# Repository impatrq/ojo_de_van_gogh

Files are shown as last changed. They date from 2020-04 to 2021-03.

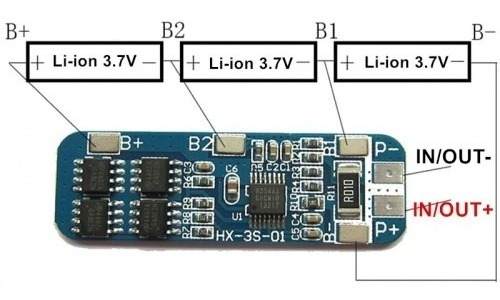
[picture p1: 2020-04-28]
modulo_de_carga/Diagrama_de_conexion/Cargador_de_pilas/Como-conectar-pilas.jpg

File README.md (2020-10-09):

# Ojo de van gogh

Este proyecto esta hecho con el fin de crear un **sistema de ayuda a la gente con discapacidad visual** para, a través de inteligencia artificial, **reconocer objectos que no pueden ver**. 

Se compone de un sistema electrónico que va colocado en el antebrazo y lleva una camera que se coloca en la mano. Cuando el ciego, por ejemplo, parpadea dos veces el sensor cerebral entiende su intencionalidad de querer sacar una foto y se lo comunica a la raspberry, esta actua sacando una foto y la procesa con **google vision API** para luego dar una respuesta del texto que se lee en la foto, el objeto que aparece o los colores predominantes

## Requisitos

Para ejecutar este proyecto se debe contar con estos requisitos:

- Hardware: elementos electronicos fisicos para crear el sistema.
  - Mindwave
  - Arduino Nano
  - Raspberry Pi Zero
  - Pi camera
  - Cargador portatil pequeño (ver PCB)
  - Dos buzzers
- Software: lenguajes requeridos para poder llevar a cabo esta idea
  - Python 3.7
  - Arduino IDE

## Instalación

#### Raspberry:

Para ejecutar la instalación debemos pararnos en la carpeta raiz del proyecto y ejecutar

```shell
pip install -r requirements.txt
```

Luego de ejecutar esto contamos con las dependencias para que la raspberry trabaje de manera correcta. 

#### Arduino:

Para ejecutar la instalacion procedemos a conectar el arduino a nuestro computador y seleccionamos el puerto correspondiente y enviamos el archivo "mindwave.ino" que se encuentra en la siguiente ruta *ojo_de_van_gogh\placa_electronica\arduino_code*

## Autores de este repositorio 

- **CARRO, Nahuel Agustín** - *PCB, Arduino y Raspberry* - [NahuelCarro](https://github.com/NahuelCarro)
- **PIERRI, Matias Gabriel** - *PCB, Arduino, Raspberry y Case3D* - [matias1379](https://github.com/matias1379)
- **VILARDO, Theo** - *Raspberry* - [TheoVilardo](https://github.com/theovilardo)
- **FONTE, Gonzalo Juan** - *Case3D* - [gonzafonte](https://github.com/gonzafonte)

## Colaboradores

- **MEDINA, Sergio** - *Supervisor desarrollo proyecto* - [sergiomedinaio](https://github.com/sergiomedinaio)

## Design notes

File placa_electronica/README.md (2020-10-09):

# Placa electrónica

Esta carpeta contiene los códigos de programación necesarios para crear el sistema, además de las conexiones para fabricar el circuito electrónico.

Vamos a encontrar las siguientes carpetas:

- **Arduino code**: Esta carpeta contiene los códigos de programación que se deben colocar en Arduino NANO usando el Arduino IDE. El código se hace utilizando la metodología de creaciones de clases de C++
  - Mindwave.ino: Este programa se va a encargar de procesar la informacion del sensor cerebral y comunicarle a la raspberry en que momento se detecto un doble pestañeo intencional del usuario
  - códigos_auxiliares_ejemplo: Aquí se encuentran códigos de programación que nos ayudaron a desarrollar el código *mindwave.ino*
- **PCB Ojo de Van Gogh**: Esta carpeta contiene los archivos de KiCAD del PCB junto a su esquemático, además cuentan con una carpeta de *huellas* con las dependencias que necesita
- **Raspberry code**: Esta carpeta contiene los códigos de programación que deben ser cargar en la Raspberry Pi Zero:
  - main.py: es el código que debe ser cargado y ejecutado en la raspberry. Se encarga de recibir la orden del Arduino NANO y generar la acción que el usuario elije previamente
  - clases: Aquí se encuentran las clases que se llaman en el main.py ya que usamos OOP
  - códigos_auxiliares_ejemplo: Aquí se encuentran códigos de programación que nos ayudaron a desarrollar el código *main.py y sus clases*

**WARNING**: Hay un .gitignore que tiene seteado que no debe subir al repositorio las **credenciales de Google Vision API** ya que es información sensible y cada uno debe colocar la credencial correspondiente al clonar el repositorio. **Si no se agrega esta credencial el main.py fallará**

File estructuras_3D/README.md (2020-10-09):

# Estructuras 3D

Esta carpeta es un apartado a las estructuras 3D que hicimos en AutoCAD 2007. Dentro de esta carpeta van a encontrar:

- **Logotipo 3D**: Aqui esta el logo en 3D para colocarlo en nuestro producto para hacer un establecimiento de la marca
- **PCB case**: Aqui estan los archivos CAD correspondientes para la estructura que va a encapsular el PCB. Notese que al abrir esta carpeta hay un CAD con la estructura completa y otros CAD que son esta misma estructura cortada al medio a fin de poder imprimir medio *case*, insertar el pcb y luego pegar la otra mitad del *case* arriba

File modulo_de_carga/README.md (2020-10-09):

# Modulo de carga

Esta es una idea en **etapa experimental** de, ademas del sistema de reconocimiento visual del ojo de van gogh, crear un cargador de baterias que indique con un sonido cuando estas se cargaron al maximo ya que el usuario con discapacidad visual no cuenta con los medios para recibir ese *feedback* de que se cargo su bateria

Dentro de esta carpeta se encuentran:

- **Diagrama de conexion**: Aqui se van a encontrar los esquematicos y pcb de este modulo de carga. Notese que hay una carpeta que contiene los simbolos y huellas que requieren estos archivos de KiCAD

- **Diseño de estructura**: Aqui se van a encontrar lo archivos CAD correspondientes al diseño de la estructura de este modulo de carga. Notese que se encuentran en dos formatos:

  - CAD(autoCAD 2007)
  - PDF

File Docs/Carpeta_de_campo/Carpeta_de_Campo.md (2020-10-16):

# Carpeta de Campo 

## Semana 15/03 - 22/03

Escribimos una declaración jurada sobre la compra del NeuroSky Mindwave debido a que Matías Pierri tuvo la oportunidad de que un conocido se lo compre en USA Y abaratar costos

> Clic [aqui](https://github.com/impatrq/ojo_de_van_gogh/blob/develop/Docs/Carpeta_Tecnica/DeclaracionSensor.pdf) para ver la Declaración Jurada

### NeuroSky Mindwave

Es una diadema con biosensores de electroencefalografía que permite hacer la medición de las ondas eléctricas del cerebro y vincularse a diferentes aplicaciones para investigación, entrenamiento cognitivo y bienestar.

El NeuroSky MindWave Mobile 2 mide y emite de forma segura los espectros de potencia EEG (ondas alfa, ondas beta, etc.), los medidores NeuroSky eSense (atención y meditación) y los sensores para el parpadeo de los ojos. El dispositivo consta de un auricular, una orejera y un brazo sensor, los electrodos de referencia y de tierra del auricular están en la pinza para la oreja y el electrodo EEG está en el brazo del sensor, apoyado en la frente sobre el ojo. 

En nuestro caso, lo vamos a usar para que cuando la persona parpadee se active el sistema.

mindwave

### Motor vibrador

Investigamos sobre vibradores y llegamos a la conclusión de que lo mas viable es reciclar vibradores de teléfonos viejos como los Nokia. Un motor vibrador es un motor común en el cual se le pone un peso en la punta del émbolo lo que lo hace vibrar, además se coloca dentro de un contenedor que aumenta la vibración.

vibrador

### Conexión entre BT y Arduino

Establecimos el entorno de trabajo BT con Arduino usando los HC-05. En base a las conclusiones confeccionamos una guía de como usar dicho entorno 

arduino_bt

> [Guía de como Establecer conexion entre BT](https://github.com/impatrq/ojo_de_van_gogh/blob/develop/Docs/Carpeta_de_campo/Guias_md/Entorno%20de%20trabajo%20de%20Arduino%20con%20Bluetooth.md)

Usando Arduino logramos hacer que funcionen los vibradores extraídos del Nokia usando la función Tone() and noTone() que te permite poner la frecuencia de vibración la cual va a variar según lo que se necesite

> [Guía de Sistema de vibracion](https://github.com/impatrq/ojo_de_van_gogh/blob/develop/Docs/Carpeta_de_campo/Guias_md/Sistema%20de%20Vibraci%C3%B3n.md)

Como la Raspberry se maneja con JSON estuvimos aprendiendo a como procesar un string JSON en Arduino y poder hacer el intercambio de datos entre Raspberry y Arduino por BT. Nos dimos cuenta que para que se lean bien los datos hay que usar Serial.readString() ya que Serial.read() solo detecta que entra un char 

> **JSON** (acrónimo de  JavaScript Object Notation, «notación de objeto de JavaScript») es un  formato de texto sencillo para el intercambio de datos.

Empezamos a trabajar con el sensor cerebral conectado a un teléfono y logramos que cuando parpadee el usuario, el teléfono lo detecte pero esto es una app y no nos permite tocarla mucho para usarla en nuestro Arduino pero era a modo de primeros pasos. Usando un modulo bluetooth y comandándolo por AT tratamos de configurarlo insertando los siguientes datos

> Baudrate = "576000"
>
> BIND ADDR= "0081,f9,29eb31"
>
> PSSW = "1234"

Con esta configuración no funciono ya que la password estaba mal puesta. Viendo la documentación nos dimos cuenta que la pass es 0000

> PSSW CORRECTA ="0000"

Ya de esta forma pudimos conectar el Arduino con el HC-05 pero con el example que nos da el fabricante solo podemos medir nivel de atención y relajación. Tenemos que investigar como medir nivel de pestañeo. Sin embargo hicimos una prueba donde se prenden leds de acuerdo a que tan concentrado esta el usuario

Establecimos el entorno de trabajo en Google Visión IA que es usar la Nube de Google para, a través de un sistema de redes neuronales, obtener un análisis de lo que se ve en una foto. Para esto tuvimos que crear un proyecto en Google Cloud Services y habilitar la api de Google Visión AI. Una vez habilitado esto nos dan un archivo JSON que tiene nuestra API Key y la insertamos en la Raspberry usando 

```Raspbian Terminal
export GOOGLE_APPLICATION_CREDENTIALS=/home/pi/filename.json
```

Una vez seteada la Raspberry se usan los siguientes comandos para instalar las dependencias necesarias

```Linux Terminal
   python3 -m pip install --user pip
   python3 -m pip install --user google-cloud-vision
   python3 -m pip install --user Pillow
   python3 -m pip install --user picamera
```

Usamos este comando para sacar una foto 

```RAspbian
   raspistill -o cam.jpg
```

Y este ejemplo para poder probar el análisis de la foto 

```Raspbian terminal
python3 camera_vision_face.py
```

Nos devuelve este análisis donde la Raspberry se encargo de detectar las personas que aparecen en la foto en este caso Theo. Lo borroso de la foto se debe a que Theo tiene el celu que no enfoca, la definición en si de la Pi Camera es bastante buena

theo

Ahora tenemos que ver como usar la Raspberry para conectarla al BT y además que todos estos programas que describimos antes estén funcionando en Loop y de forma automática cuando se prende la Raspberry.

## Semana 22/03 - 29/03

Estuvimos viendo documentaciones y aparentemente para poder leer el valor de Blink Strength tenemos que escribir en el registro **0x16** 

registros_mindwave

Se hicieron ejemplos con Arduino para empezar a leer los datos Json que se recibirán de la Raspberry. Se han hecho pruebas de como formar un Json y como obtener el valor de Json.
Luego se probo mandar archivos String por BT, pero nos dimos cuenta que la función no permite mandar Strings por BT:

```
BTMaster.write()
```
Se ha visto varios videos o formas de intentar mandar el String por BT de otra forma, pero no se ha conseguido, entonces se empezó a investigar para pasar un String a un char Array. Se ha encontrado un ejemplo en el que muestra que la función: 
```
str.toCharArray(charArray,buf)
```
Siendo str el String ingresado, charArray, la variable donde se guarda el charArray y buf la cantidad máxima a convertir de String en char Array.

Se ha tenido problemas con esta función ya que dependiendo del orden en el que se declaraba el String, funcionaba o no. Pero se ha logrado descubrir el error, creando 2 programas: 
-	Uno que simula el parpadeo, sacar foto y mandar el String Json por BT a través de un charArray
-	El otro que recibe el char Array y lo convierte en un String, y obtiene el valor del Json de color y de acuerdo al color realiza una vibración

> [Sistema de vibraciones con Json y BT](https://github.com/impatrq/ojo_de_van_gogh/blob/develop/Docs/Carpeta_de_campo/Guias_md/Sistema%20de%20vibraciones%20de%20acuerdo%20al%20color.md)

Hemos realizado el logo para el proyecto:



## Semana 29/03 al 05/04
Se crearon las piezas en 3D del cargador de pilas. Las piezas están diseñadas teniendo en cuenta las plaquetas que van a ir colocadas y están los agujeros para los respectivos cables.

**Cargador parte 1**

cargador_1

**Cargador parte 2**

cargador_2

**Cargador parte 3**

cargador_3

Analizamos el problema que creamos en el repositorio de Ojo de Van Gogh ya que nos mezclamos con el manejo de branches y mil problemas entonces decidimos crear repositorios por cada área de trabajo del proyecto y los archivos de documentación y publicidad manejarnos por drive. 
Los repos quedan de la siguiente manera:

- Mindwave
- ArduinoVibrador
- Raspberry
- Cargador de pilas

Ahora nos manejamos con ramas donde la versión final y estable del repo va a Máster y luego cada feature se desarrolla en una rama paralela. Luego de hacerle el testing a la misma y ver que no hayan conflicto se hace un merge (se fusiona la rama con el máster y se cierra la rama)

Con respecto al mindwave decidimos poner en pausa el código del micro porque nos estábamos perdiendo con el tema del payload. Encontramos varios repos en github con los códigos en Python donde al ejecutarlos te otorgan los datos. El plan es conectar por BT el mindwave a la computadora y correr el script. Una vez que el mismo este listo 

Nos estamos contactando con varias empresas preguntando sobre plaquetas flexibles para el sistema de vibración aunque también se esta evaluando la opción de utilizar los brazaletes porta celulares para correr. Se ha realizado el PCB del sistema ya que una empresa nos contacto y nos lo pidió para saber el tamaño y complejidad.

## Semana 05/04 al 12/04

Hemos recibido las respuestas de las empresas por plaquetas flexibles y nos ha parecido muy elevados los costos por lo cual optamos por usar un brazalete para celulares de un tamaño de 18cm x 10 cm y se ha realizado el esquemático del circuito donde estará la Raspberry con la cámara, el Arduino Nano, el Bluetooth, dos pilas, un regulador y los vibradores.

Hemos calculado el consumo total del circuito para saber que tenemos que usar dos pilas de 3.7V ya que con una nos duraría poco tiempo, y por esto se ha investigado sobre Step down, ya que tiene mejor rendimiento que un regulador, ya que se necesitan 5V de entrada en vez de los 7.4V que nos dan las dos pilas en serie.

También se ha realizado una librería para los colores en Arduino, y hemos encontrado el problema que si haces un archivo con la extensión:  ".c " salta un error y se soluciono esto cambiando la extensión del archivo a ".cpp"

Se ha investigado sobre el mindwave y el funcionamiento de un programa y se ha conseguido que se detecte el parpadeo pero también se detecta el parpadeo no forzado y para eso estamos viendo como solucionarlo.

Se ha conseguido que la Raspberry nos entregue el color en RGB con Json

Se ha comprado un dominio y estamos haciendo la pagina web a través de un localHost (Xampp) y usando WordPress. Se ha elegido el tema de la pagina que es BlackootLite.
## Semana  12/04 al 19/04

Se ha terminado el PCB de la placa

Montamos el host en 000webhost que nos ofrece 300 Mb de espacio y le instalamos wordpress. Tuvimos problemas con el dominio así que contactamos a soporte técnico de hostinger y nos solucionaron el problema.

> Clic  [aqui](https://ojodevangogh.tech) para entrar a nuestra pagina

Encontramos un modulo de Python que pasa de RGB a nombre de color y funciona pero tienen sus limitaciones. El tema es que no da resultado a todos los RGB sino a los que son fáciles tales como  0,0,0 que da black pero si le metemos algo como 65,23,19 ya se pierde.

Encontramos una alternativa basándonos en la página de un sensor de color que nos otorga Luis llamas 

> [Sensor para Detectar colores](https://www.luisllamas.es/arduino-sensor-color-rgb-tcs34725/)

Acá muestra un sensor para detectar colores y en esta usan una librería que pasa los valores RGB a HSV que nos permite saber las distintas tonalidades de un color ya que distingue de rojo oscuro y rojo claro y nos permite tomas los dos como rojo. Esta librería la pasamos a Python y gracias a esto ya poseemos 12 colores identificables

Hemos realizado la librería para la vibración de los colores y para esto hemos creado una tabla para determinar la vibración de cada color:

**Lista de colores para vibración**

- El número 0 representa 0.25 segundos de duración de vibración
- El número 1 representa 1 segundo de duración de vibración 
- Entre cada numero hay 0.25 segundos de pausa
| Código | Colores  |
| :----: | :---: |
|  0000  |  Blanco  |
|  0001  | Rojo |
|  0010  |  Marrón  |
|  0011  | Naranja  |
|  0100  | Amarillo |
|  0101  |  Verde |
|  0110  | Cian |
|  0111  | Azul |
|  1000  | Violeta  |
|  1001  | Rosa |
|  1010  | Gris |
|  1011  | - |
|  1100  | - |
|  1101  | - |
|  1110  | - |
|  1111  |  Negro |

La pagina web se nos cayó. Nos suspendieron la pagina porque aparentemente superamos el limite de visitas al entrar a verla y nos dicen que si no pagamos en 7 días nos la borran.

Nos comunicamos con webhost a ver si hay alguna alternativa pero no nos contestan así que no nos queda otra que pagar y mudarnos a hostinger

**Logo 3D**

Se ha hecho el logo en formato 3D para después agregarlo como marca en la caja que tengamos.

logo_3D

## Semana 19/04 al 25/04

Pagamos la migración de nuestro página a hostinger que nos salió 10 dólares. Tenemos que esperar 48 hs a que nos digan si salió todo bien y no perdimos la pagina.

Recuperamos la pagina y esta todo en orden aunque se nos desconfiguró el dominio y tenemos que cambiarlo así responde a ojodevangogh.tech . Eso si, no podemos entrar al panel de wordpress por alguna razón.

Nos comunicamos con hostinger y después de unos largos idas y vueltas de email mudamos completamente la pagina ya no tenemos nada en webhost esta todo en hostinger y funciona todo. Habilitamos la certificación ssl así que nuestro pagina es segura y ya tenemos acceso al panel de wordpress. 

Tenemos un problema en el responsive desing que hace que desaparezcan los botones de la página cuando usamos una versión mobile y no sabemos que hacer

## Semana 25/04 al 3/5

Vimos que no había manera de solucionar el responsive design mas que pagar el upgrade del theme de wordpress a premium que son 40 dólares así que decidimos cambiar de tema de Wordpress. 

Empezamos la búsqueda y encontramos uno llamado astrid que esta muy bueno visualmente y tiene mucha opción de personalización. Lastimosamente no podíamos cambiarle el fondo blanco así que para que no queme tanto le colocamos letra Arial que es mas gruesa y llama la atención.

Le instalamos un plugin a la pagina para que aparezcan botones que vinculen la página con Instagram, LinkedIn llamado UltimateShare.

Creamos una pagina de Instagram para empezar a subir cosas y ya grabamos unos videos de como la Raspberry reconoce colores y como a través de un color seleccionado funcionan los vibradores

Para un mejor orden creamos un repositorio nuevo donde metimos todas las cosas de los pequeños repos a través de git flow que permite ordenar todo en feature.

Para armar cosas lindas para redes sociales hicimos que la plaqueta tenga todos los micros y cosas con modelos 3D así verlos con el visor 3D de KiCAD

## Semana 03/05 al 11/05

Se hizo una introducción para el video en After Fx, se le puso música de fondo y se subió a Instagram y a la pagina web el primer video mostrando como se reconoce el color con la cámara de la Raspberry

También se definió el modelo para hacer la tapa del cargador de pila y se empezó a hacerla. 

Se agregó un plugin para que la pagina cargue mas rápido y se corrigió el logo para que no sea de fondo blanco y pueda verse. 

## Semana 11/05 al 18/05

Se empezó a intentar conectar la Raspberry con el sensor cerebral y se configuro esta para que trabaje por Remote

Agregamos con gtts para que se pueda escuchar el color y lo probamos con un parlante y anduvo. Para traducir el texto color a voz se creo una nueva función que envía archivo txt que los recibe el gtts y los reproduce en un parlante

Para la PRIMER ENTREVISTA DE RADIO, se realizo una tarjeta publicitaria que se subió a Instagram y como se escucho bajo, se edito el  audio grabado y se preparó para subirlo a IGTV y quedamos en que cuando la situación del país lo permita, nos volveremos a juntar para contar los nuevos avances.

Se daño el disco de la computadora y perdimos lo que teníamos hecho de la tapa y no se había subido a git.

## Semana 18/05 al 25/05

Se pudo conectar el sensor cerebral con la Raspberry pero no lee el payload del Mindwave y estamos con ese problema que no sabemos como resolverlo

Se hizo un Backup de la pagina web porque se nos vencía el mes de Hostinger pero debido a un error que tuvieron nos regalaron un mes y ya elegimos que para el mes próximo vamos a cambiar al host de Sitio Hispano que nos saldría $860 el año ya que no se puede pagar por mes

Estuvimos pensando y se nos ocurrió que nuestra pagina tiene que tener para que los ciegos la puedan leer, entonces agregamos el Plugin Responsive Voice que permite a través de un botón reproducir el contenido de cada pagina.

Se edito y subió el IGTV de la nota de radio y también subimos el link de la pagina que hizo la radio FM106.5 sobre esta nota. 

Se terminó la tapa y se empezó a realizar el encastre en la caja.

Se crearon archivos txt para el gtts para optimizar los tiempos de respuesta cuando se reproducen los colores, ya que lee los archivos creados en vez de crearlos y después leerlo.

## Semana 25/05 al 1/06

Se logró la comunicación entre el Arduino y la Raspberry y creamos 2 librerías una para detectar colores y otra para crear un JSON. Esto se hizo para ordenar el código. A la librería de detectar_colores también se le incorporó los audios para reproducir el color. 

Se investigó como hacer que cada vez que la Raspberry se enciende empiece a correr el script automáticamente sin ponerle el comando utilizando Crontab.

> [Script para automatizar inicio](https://github.com/impatrq/ojo_de_van_gogh/blob/develop/Docs/Carpeta_de_campo/Guias_md/Correr%20script%20cada%20vez%20que%20se%20prenda%20la%20Raspberry.md)

Se ha logrado pasar las fotos a formato base64 para reducir tiempos de espera y se logro una optimización. Antes tardaba 24 segs y ahora tarda entre 16 y 20 segs, siendo un factor clave la luz ambiente, ya que si hay poca luz tarda mas. 

Se ha investigado e implementado en la página web sobre plugins de accesibilidad, se han probado varios pero el que mas herramientas nos proporciona es UserWay, Este plugin tiene varias herramientas
- Permite 3 niveles de lector de pantalla(medio, rápido y despacio).
- Navegar por teclado (accesibilidad para ciego y poca motriz)
- Cambiar los contrastes de fondo (gris, invertido, oscuro y claro)
- Permite resaltar enlaces
- Aumentar el tamaño y el espaciado del texto y también del cursor
- Detener animaciones
- Cambiar la letra para la gente que padece dislexia
- Aumentar el cursor y tener una guía de lectura
- Y por ultimo ofrece resetear todas las opciones

accesibilidad

Se ha avanzado con el modelado 3D de la caja que contiene el proyecto, modificando los espacios para las pilas ya que no iban a entrar con el que tenía y se avanzó con el encastre de la tapa con la caja agregando los agujeros en la misma. 

## Semana del 1/06 al 8/06

Se editó y musicalizó un segundo video para subir a las redes , el cual mostrara como al reconocer un color empezaría a reproducirse un sonido/vibración.

Se subió a ig historias de quienes somos y una breve descripción del proyecto, dejando estas mismas como destacadas y se aumento 16 seguidores .

Se hicieron varias pruebas para empezar a reconocer texto y con el código que ofrece la api no lográbamos poder reproducir el texto, entonces hemos buscado otro código el cual nos permitió reproducir el texto que reconoció de la imagen que le cargamos a la Raspberry

Se han buscado diferentes librerías para hacer una lectura de OCR mas rápida pero no se encontró, y viendo videos y características, hemos decidido pasar de la Raspberry Pi Zero w a la Raspberry Pi 3 y hemos tenido las siguientes mejoras:
- Reconocimiento de colores en  5 segs
- Reconocimiento de texto entre 7 y 11 segs
- Reconocimiento de objetos en 10 segs

Se hizo un código para reconocer objetos obteniendo el objeto con mayor seguridad. Se ha agregado para que el objeto sea traducido ya que la librería da el resultado en ingles. Hemos aprovechado esto para darle una herramienta mas al proyecto y permitir que cuando una persona quiera leer texto que no sea español, sea traducido y sea reproducido por el auricular. 

Se ha instalado el plugin Yoast que sirve para saber que características faltan para mejorar el SEO de la pagina (optimización de los buscadores). Luego se ha procedido a cambiar la página de inicio agregando información y cambiando títulos de acuerdo a la palabra clave ingresada "ciego ven colores". 

Debido a que la actividad cerebral de cada persona es distinta y no se puede tomar una medida precisa para usar cuando se parpadea, hemos empezado a investigar sobre desviación estándar.
Para ver el grafico de la desviación estándar se investigo sobre la librería pandas pero después vimos que no era necesario y teníamos problemas con el ajuste de escala. 
Se hizo un graficador de las ondas cerebrales a través de Arduino usando Matplotlib y hemos visto que la desviación estándar con 2 parpadeos no es tan estable ya que varia entre 50 y 60 pero cuando la persona parpadea 3 veces es mucho mas estable dando unos valores de 80. 

Se termino con el diseño 3D de la caja y tapa agregando un encastre para que entre a presión, quedando lista para su impresión. 

### Tapa de la caja

tapa_caja

### Caja por dentro

caja

## Semana del 8/06 al 15/06

Se crearon librerías para tener el código mas prolijo.
- Librería de reconocimiento de texto tanto en español como en otro idioma, ya que tiene la opción de que cuando se reconozca que es otro idioma sea traducido 
- Librería de reconocimiento de objetos, dando el contenido en español. 

Se agrego para que se pueda reconocer la ubicación de dichos objetos detectados y limitando a que te diga solo los que la api detecta con una buena precisión (score). 

Se ha mejorado la pagina "El proyecto", basándonos en las características de mejorar la legibilidad y algunas cuestiones de SEO. 

## Semana del 15/06 al 22/06

Se grabo un video mostrando el reconocimiento de colores, objetos y leyendo un texto. Luego se agregaron efectos especiales

Se hizo una publicación para IG por la entrevista que tuvimos el viernes, y se edito el video , musicalizo y se subió a IGTV . Nos hemos contactado con ASAC y estamos esperando la respuesta. 

Mudamos la pagina a un nuevo host (SitioHispano) que nos salió 860 $ el año

Se ha detectado cuando entra información del Mindwave para tomar el valor promedio de la persona en los primeros segundos.

Se adapto para que se reconozcan los 2 colores que mas ocupan en la foto y luego ordenarlo para que primero este el que mejor se reconoció (score mas alto). 

Se actualizo la librería de objetos, agregándole la ubicación del mismo

## Semana del 22/06 al 29/06

Se hizo una librería para el código de Mindwave para que quede mas ordenado.

Se incluyo en la librería de RGB para que se pueda reconocer 2 colores si la diferencia de score es menor a 0.10 

En la pagina web, agregamos los slider en la paginas de noticias para que sea mas cómodo y lindo.

Se hizo el anuncio para la radio 99.3 FM que sale el viernes y se ha publicado con la edición de musicalización el tercer video mostrando el reconocimiento de colores, texto y objetos

Se nos ocurrió para mejorar la calidad del reconocimiento de colores, crear una tabla de Excel y copiar los 140 colores que nos da la pagina de Wikipedia con sus RGB y sus nombres. Luego exportamos esa tabla a pandas y hemos agregado 2 condiciones para los colores negro y blanco.

## Semana del 29/06 al 06/07

Se subió el IGTV de la entrevista de la radio y también se ha subido a YouTube y a la pagina web.

Se agrego dos condiciones de blanco y negro para descartar mas rápido y si no se cumplen que recorran el código a través de búsqueda binaria en Rojo, haciendo que el código sea mas rápido.

Hemos puesto que si no se encuentra algún color en la tabla, se agregue ese valor a la misma .Luego será revisado por alguno de los integrantes, clasificándolo y quedando la tabla ya actualizada.

También hemos probado algunas fotos y clasificando los colores que no se han reconocido.

## Semana del 06/07 al 14/07

Se incluyo en la pagina web un mensaje de bienvenida y también un nuevo símbolo cuando las paginas están cargándose.

Se ha contactado nuevamente con ASAC y MasScience y nos prometieron publicar pronto un articulo nuestro en su pagina. Se ha mandado mails tanto a medios nacionales como radios.

Se normalizaron todos los códigos haciendo que todos queden con la misma estructura de pedir el dato a obtener: color, texto u objeto.

Se ha creado una clase de búsqueda binaria y ordenado el main. Se creo una nueva clase llamada Google Vision Engine .
En esta clase se han creados los métodos de 

- Pedir color
- Elegir ese color(query)
- Leer texto y reproducirlo
- Reconocer objetos y su ubicación

Nos hemos dado cuenta de que muchas variables y partes de código que no se usaban y las hemos borrado.

Hemos agregado para que cada valor nuevo en la tabla, se reorganice de menor a mayor y se actualicen los id 

Se preparo la encuesta en Google forms  para saber que piensan las personas sobre el proyecto.

## Semana del 14/07 al 21/07

Se ha realizado nuevamente el PCB, ya que hemos agregado el switch de 4 posiciones para que la persona elija una función del proyecto. También se ha reemplazado las pilas de litio y regulador de tensión y pusimos una entrada para un cargador portátil común.

**PCB Terminado**

placa

pcb

esquematico

Se ha investigado para agregar que se corrijan las palabras cuando se las reconoce mal pero con la librería Textblob era muy irregular y decidimos no usarlo.

Se paso el código de vibración, realizado en Arduino a Python para controlar el buzzer con la Raspberry. Esto se realizo ya que si quisiéramos que el Arduino realice las vibraciones, se pierde tiempo para captar la señal que proviene del Mindwave. También se creó una función para que se pase de texto a audio

Se realizo la encuesta y hemos sacado buenas conclusiones sobre los datos obtenidos a través de las respuestas.

## Semana del 21/07 al 28/07

Semana de descanso por receso escolar de invierno.

## Semana del 28/07 al 04/08

Hemos investigado sobre lo que seria nuestro cliente ideal y tareas que quiera realizar, observando los beneficios y miedos o frustraciones de realizar dicha tarea. Una vez realizado esto, hemos planteado sobre las situaciones que le dan alegría y tristeza al cliente y que ofrecemos nosotros como producto y servicio.

Vamos a empezar a realizar entrevistas a personas con ceguera y hemos planteado como tienen que realizarse, lo que no hay que hacer y recomendaciones.

Hemos encontrado una tabla con 865 colores con sus nombres, valores hexadecimales y valores R,G,B y hicimos un código con dicha tabla buscando el color en la tabla que tenga menos diferencia con el color buscado.

Nos ha contactado la página de MasScience para decirnos que publicaron en su página un artículo sobre nuestro proyecto. 

> Clic  [aqui](https://www.masscience.com/2020/07/21/proyecto-ojo-de-van-gogh/) para ver el artículo del proyecto

## Semana del 04/08 al 11/08

Se ha creado el método de audio y se agrego a la clase principal llamada Google Vision Engine, que es la clase que contiene todos los métodos. Una vez agregado la clase de audio se ha usado en los métodos de texto, objetos y color, para que se reproduzca por un parlante, el parámetro que se pida .

También nos hemos contactado con algunas personas que padecen ceguera para poder hacerles una entrevista y verificar cuales son los problemas principales de estas personas en el día a día, y con esto nos han confirmado lo siguiente:
- Ellos se frustran no tener un sentido asociado al color y se preguntan que es, y al vivir en un mundo que se ve tienen que saber como vestirse pero para ellos es lo mismo la combinación de colores. También buscan relacionar los colores con objetos, por ejemplo que el rojo es del fuego
- Les molesta cuando las situaciones no tienen audios descriptivos. Y para cuando tienen que ir a comprar necesitan alguien que les diga cuanto sale y cuando es la fecha de vencimiento
- El reconocimiento de objetos para ellos es muy importante, ya que no pueden saber que hay cuando les mandan una foto, y si quieren ir a comprar necesitan de alguna persona para saber donde esta lo que ellos buscan.

## Semana del 11/08 al 01/09

Semanas para rendir exámenes y entrega de trabajos prácticos.
Hemos hablado de los pasos a seguir del proyecto:

- Armar guion y video para presentar el proyecto
- Hacer un diagrama de arquitecturas para organizar el código.

## Semana del 1/09 al 8/09

Luego de haber hablado con el profesor durante varias semanas de como seguir y que mejoras tendríamos que hacer, hemos empezado por reorganizar el código. Para eso hemos armado un diagrama de arquitecturas definiendo todas las clases padres e hijas

diagrama_arquitecturas

Hemos traducido el dataset de 860 colores para evitar traducirlo y hacer que el código sea mas rápido 

## Semana del 8/09 al 15/09

Hemos realizado el refactoring de la clase de colores y un conteiner de Docker para poder hacer un despliegue a producción

Hemos empezado a investigar sobre como se arma un video para poder presentar nuestro proyecto y hemos planteado los puntos principales que tiene que tener este.

## Semana del 15/09 al 22/09

Hemos realizado el refactoring de la clase de objetos y de la clase de texto, que heredan de la clase Google Vision Engine, que tiene como parámetros el cliente y la imagen que se saca con la cámara de la Raspberry.  También se empezó a armar el guion.

## Semana del 22/09 al 29/09

Hemos realizado el refactoring de la clase de audio que es la que se encarga de pasar de texto a audio y reproducirlo. A esta clase se le pasa un parámetro que puede ser: los colores, los objetos o el texto y lo reproduce por audio. 

También se hizo el refactoring de la clase que se encarga de realizar una vibración para el color. A esta clase se le pasa como parámetro el nombre del color que se reconoció y de acuerdo a la tabla de vibración se hará la vibración. 

Se ha terminado de armar el guion para el video, en el cual se detallan que tiene que durar entre 2 y 3 min, y hay 2 voces en off que irán explicando la problemática que tienen las personas con ceguera y cual es la solución que ofrecemos nosotros, mostrando los videos que hemos realizado donde se puede observar el reconocimiento de objetos, lectura de texto y reconocimiento de color con otro video que muestra como será la vibración de un determinado color.

## Semana del 29/09 al 06/10

Hemos realizado el main.py usando todas las clases que ya armamos las semanas pasadas, y hemos puesto para que si se detecta un parpadeo dependiendo de lo que se pida se obtenga ese parámetro.

Hemos ordenado las carpetas de GitHub y realizado los distintos Readme para saber de que se trata cada carpeta y se empezó a probar una plataforma, Animaker, para realizar la animación que irá acompañada del guion armado.

**Prueba de la animación para el video**

animacion

## Semana del 06/10 al 13/10

Hemos empezado a crear columnas con los nombres de los colores principales para pasar a la función de vibrar, mientras que por audio saldrá el nombre completo, por ejemplo: rojo será para la vibración mientras que por audio saldrá rojo morado.

Se ha grabado el video para presentar el proyecto y se empezó a realizar la animación para mostrar la problemática del ciego y la solución que ofrecemos con el proyecto. También se ha realizado el informe descriptivo del proyecto.

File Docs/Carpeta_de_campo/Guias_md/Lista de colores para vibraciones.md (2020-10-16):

## Lista de colores para vibración

- El número 0 representa 0.25 segundos de duración de vibración
- El número 1 representa 1 segundo de duración de vibración 
- Entre cada numero hay 0.25 segundos de pausa
| Codigo | Colores  |
| :----: | :---: |
|  0000  |  blanco  |
|  0001  | rojo |
|  0010  | marron |
|  0011  | naranja |
|  0100  | amarillo  |
|  0101  |  verde  |
|  0110  |  cyan  |
|  0111  |  azul  |
|  1000  |  violeta  |
|  1001 |  rosa  |
|  1010 | gris |
|  1011 | - |
|  1100 | - |
|  1101 | - |
|  1110 | - |
|  1111 | negro  |

```python
def rgb_to_hsv(r, g, b):
    r, g, b = r/255.0, g/255.0, b/255.0
    mx = max(r, g, b)
    mn = min(r, g, b)
    df = mx-mn
    s = (df/mx)*100
    v = mx*100
    if mx <= (25/255):
      print("negro")
    if ((mx >= (226/255)) and (mn >= (226/255))):
      print ("blanco")
    if ((v>25) and (v<=60) and (s<=10)):
      print ("gris")
    if ((mx == r) and (s>=50) and (v>=30) and (v<=60)):
      print ("marron")
    if mx == mn:
        h = 0
    elif mx == r:
        h = (60 * ((g-b)/df) + 360) % 360
    elif mx == g:
        h = (60 * ((b-r)/df) + 120) % 360
    elif mx == b:
        h = (60 * ((r-g)/df) + 240) % 360
    if mx == 0:
        s = 0

    return h, s, v

print(rgb_to_hsv(226, 226, 226))
print(rgb_to_hsv(152, 137, 137))
print(rgb_to_hsv(79, 43, 27))
print(rgb_to_hsv(25, 25, 25))
```

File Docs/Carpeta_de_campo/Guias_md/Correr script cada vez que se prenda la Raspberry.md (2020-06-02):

# Correr script cada vez que se prenda la Raspberry

Desde remote.it se entra a la raspberry y por ssh usando Putty se realizo todo esto:

Se crea un archivo :

```bash
nano script_automatico.sh # con esto se crea el archivo y entramos
```

Luego adentro del script se escribe:

#!/bin/bash  Esta línea define qué shell utilizaremos, que es el Bash de shell en nuestro caso.

python3 main.py lo que hace es ejecutar el main.py que es donde esta el codigo que da el color en Json

```bash
#!/bin/bash 

python3 main.py 
```

Tocamos control O para guardar el archivo, enter y luego control X para salir

Para que el archivo sea ejecutable y no muestre que no tiene permisos se usa:

```bash
chmod +x ./script_automatico.sh
```

Luego se ejecuta para probar que el programa ande, con:

```bash
./script_automatico.sh
```

## Usar Crontab

Se ejecuta en el terminal

crontab -e , en nuestro caso elegimos nano, osea 1, y ahi se escribe:

```bash
@reboot /home/pi/script_automatico.sh
```

Con este se indica que cada vez que se reinicie la Raspberry, se iniciara el script_automatico.sh que este ejecuta el main.py

Para reiniciar la Raspberry se usa el comando **<u>sudo reboot</u>**

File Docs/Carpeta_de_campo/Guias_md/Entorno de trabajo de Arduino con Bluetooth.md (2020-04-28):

# Entorno de trabajo de Arduino con Bluetooth

Los dispositivos Bluetooth(BT) pueden ser configurados para que trabajen como Esclavo (slave) o maestro (master). 

## Modulo BT HC-05 como esclavo :
En este modo el dispositivo espera que un BT master se conecte a el.
## Modulo BT HC-05 como maestro:
En este modo, el HC-05 es el que inicia la conexión. Se utiliza este modo para comunicarse entre módulos BT.

## <u>Modos de trabajo:</u>
Tiene 4 estados :

1. Estado desconectado:
   - Entra en este estado cuando se alimenta al modulo y no ha realizado una conexión Bt. 
   - El Led del BT parpadea rápidamente.
   - El HC-05 no pude interpretar comandos AT

2. Estado conectado o de comunicación:
	- Entra cuando hay una comunicación con otro dispositivo BT.
	- El Led hace doble parpadeo
	- Los datos ingresados por el pin Rx se transmiten por BT al dispositivo conectado y los datos recibidos se devuelven por el pin Tx 

3. Modo AT 1
	- Para entrar a este estado después de conectar y  alimentar el modulo es necesario apretar el botón del modulo.
	- Se  pueden enviar comandos AT, pero a la misma velocidad que esta configurado
	- Parpadea rápido igual que en el estado desconectado.

4. Modo AT 2
	- E modulo debe encender con el botón presionado, después de haber encendido se puede soltar y permanecerá en este estado.

- En este estado, para enviar comandos AT es necesario hacerlo a la velocidad de 38400 baudios.

- EL LED del módulo en este estado parpadea lento.
## <u>Conexión para configuración del modulo Bluetooth:</u>

La conexión entre la PC y el modulo de forma directa es usando un conversor USB-Serial:

 Conexion HC-05 y conversor USB a TTL 

## Configurando el modulo HC-05
Lo haremos en el modo AT 2 , manteniendo presionado el botón hasta alimentar el modulo. Se abre el Monitor Serial del IDE de Arduino y se elige "Ambos NL y CR" y la velocidad "38400 baud".

Primero se debe hacer el test de comunicación mandando AT y el monitor serial debe responder "Ok". 

##  Configurando nuestro módulo HC-05 como esclavo:
- Entrar en modo AT 1 o Modo AT 2
- Verificar si estamos en modo AT
Enviar: AT
Recibe: OK

- Establecer el Role como Esclavo
Enviar:  AT+ROLE=0
Respuesta: OK

- Configurar el Nombre del modulo
Enviar: AT+NAME= BTSlave
Respuesta: OK

- Establecer el Pin de vinculación
Enviar: AT+PSWD="1379"
Respuesta: OK

- Configura la Velocidad de configuración
Enviar: AT+UART=9600,0,0
Respuesta: OK

- Obtener la dirección de nuestro modulo bluetooth
Enviar: AT+ADDR?
Respuesta: +ADDR:<dirección>

Para verificar los datos cambiados se le agrega un "?":
Enviar: 
AT+ROLE?
AT+PSWD?
AT+UART?
AT+ADDR? 
Respuesta:
+ROLE:0
OK
+PSWD:1379
OK
+UART:9600,0,0
OK
+ADDR: 0019:09:037236
- Resetear el modulo para que salga del modo AT
Enviar: AT+RESET
Respuesta: OK

## Configurando nuestro modulo como maestro 
- Entrar en modo AT 1 o Modo AT 2
- Verificar si estamos en modo AT
Enviar: AT
Recibe: OK

- Establecer el Role como Maestro
Enviar:  AT+ROLE=1
Respuesta: OK

- Configurar el Nombre del modulo
Enviar: AT+NAME=BTMaster
Respuesta: OK

- Establecer el Pin de vinculación
Enviar: AT+PSWD="1379"
Respuesta: OK

- Configura la Velocidad
Enviar: AT+UART=9600,0,0
Respuesta: OK

- Configurar el modo de conexión para un dispositivo especifico
Enviar: AT+CMODE=0
Respuesta: OK

- Especificar la dirección del dispositivo a conectarse
Enviar: AT+BIND=0019:09:037236
Respuesta: OK

- Verificar los parámetros cambiados
Enviar: 
AT+ROLE?
AT+PSWD?
AT+UART?
AT+CMODE?
AT+BIND?

Respuesta:
+ROLE:1
OK
+PSWD:1379
OK
+UART:9600,0,0
OK
+CMOD:0
OK
+BIND:0019:09:037236
OK

- Resetear el modulo:
Enviar: AT+RESET
Respuesta: OK

## Primeras pruebas del modulo Bluetooth Slave controlado con el celular:

Con el siguiente programa a través de la aplicación del celular "Android bluetooth controller", se recibe en el serial de Arduino lo que se escribió en el celular.
Para eso debemos entrar a la aplicación, prender el bluetooth y seleccionar el dispositivo bluetooth a conectarse (BTSlave) y seleccionar el modo "Terminal mode" y las palabras que se escriban allí aparecerán en el Serial de Arduino.
[Primer programa con Bluetooth](https://github.com/matias1379/Ojo-de-van-gogh/tree/Sistema-de-vibracion/bt1)

El segundo programa que probaremos hay que entrar en la aplicación y seleccionar nuestro dispositivo bluetooth y seleccionar el modo Switch Mode y configurar que el verde es el estado "1" y el rojo el estado "0". Con este programa lo que hacemos es prender y apagar el led interno del Arduino que está en el pin 13.
[Prueba de encendido de un led con Bluetooth](https://github.com/matias1379/Ojo-de-van-gogh/tree/Sistema-de-vibracion/bt2)

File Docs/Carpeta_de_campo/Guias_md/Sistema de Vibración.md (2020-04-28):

# Sistema de Vibración

Este sistema consta de un motor vibrador y un arduino nano. 
El siguiente programa lo que realiza es recorrer las diferentes frecuencias cada un segundo a traves de un for, usando el pwm del arduino nano.
[Primera prueba de vibración](https://github.com/matias1379/Ojo-de-van-gogh/tree/Sistema-de-vibracion/vibrador)

En el segundo programa se realizo que a traves de los valores "1,2,3" haga una determinada frecuencia por un determinado tiempo, repitiendo esto 4 veces.  Con esta prueba se representa a traves de los numeros , los colores que llegarian por la Raspberry.
[Prueba de colores y vibración](https://github.com/matias1379/Ojo-de-van-gogh/tree/Sistema-de-vibracion/colores_y_tonos)

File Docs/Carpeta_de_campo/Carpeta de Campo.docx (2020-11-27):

Carpeta de Campo

Semana 15/03 - 22/03

Escribimos una declaración jurada sobre la compra del NeuroSky Mindwave debido a que Matías Pierri tuvo la
oportunidad de que un conocido se lo compre en USA Y abaratar costos

Clic aquí (https://github.com/impatrq/ojo_de_van_gogh/blob/develop/Docs/Carpeta_Tecnica/DeclaracionSensor.pdf) (https://github.com/impatrq/ojo_de_van_gogh/blob/develop/Docs/Carpeta_Tecnica/DeclaracionSensor.pdf)para ver la Declaración Jurada

NeuroSky Mindwave

Es una diadema con biosensores de electroencefalografía que permite hacer la medición de las ondas eléctricas del cerebro y vincularse a diferentes aplicaciones para investigación, entrenamiento cognitivo y bienestar.

El NeuroSky Mindwave Mobile 2 mide y emite de forma segura los espectros de potencia EEG (ondas alfa, ondas beta, etc.), los medidores NeuroSky eSense (atención y meditación) y los sensores para el parpadeo de los ojos. El dispositivo consta de un auricular, una orejera y un brazo sensor, los electrodos de referencia y de tierra del auricular están en la pinza para la oreja y el electrodo EEG está en el brazo del sensor, apoyado en la frente sobre el ojo.

En nuestro caso, lo vamos a usar para que cuando la persona parpadee se active el sistema.

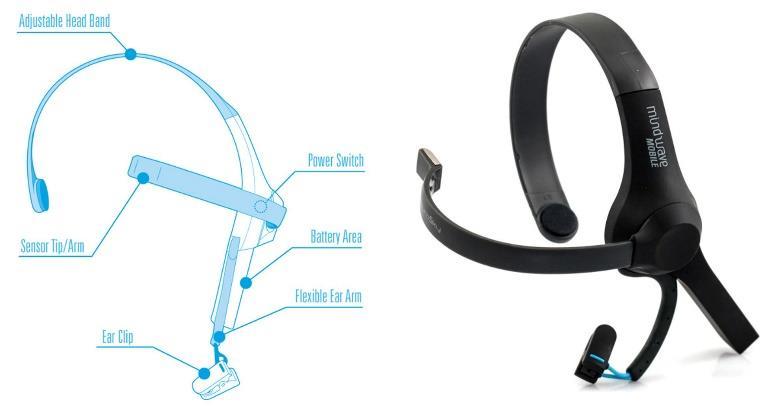
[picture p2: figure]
MindWave Mobile Electroencephalography Device (Neurosky, Inc.) | Download Scientific Diagram

Motor vibrador

Investigamos sobre vibradores y llegamos a la conclusión de que lo más viable es reciclar vibradores de teléfonos viejos como los Nokia. Un motor vibrador es un motor común en el cual se le pone un peso en la punta del émbolo lo que lo hace vibrar, además se coloca dentro de un contenedor que aumenta la vibración.

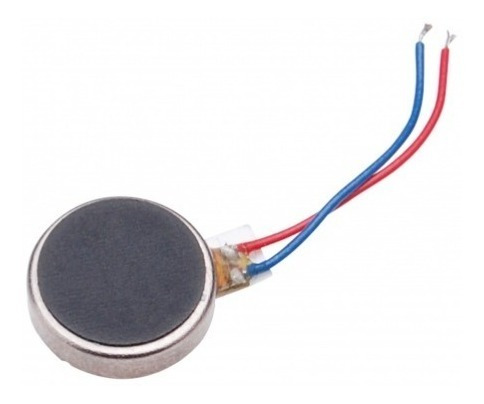
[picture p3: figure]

Conexión entre BT y Arduino

Establecimos el entorno de trabajo BT con Arduino usando los HC-05. En base a las conclusiones confeccionamos una guía de cómo usar dicho entorno

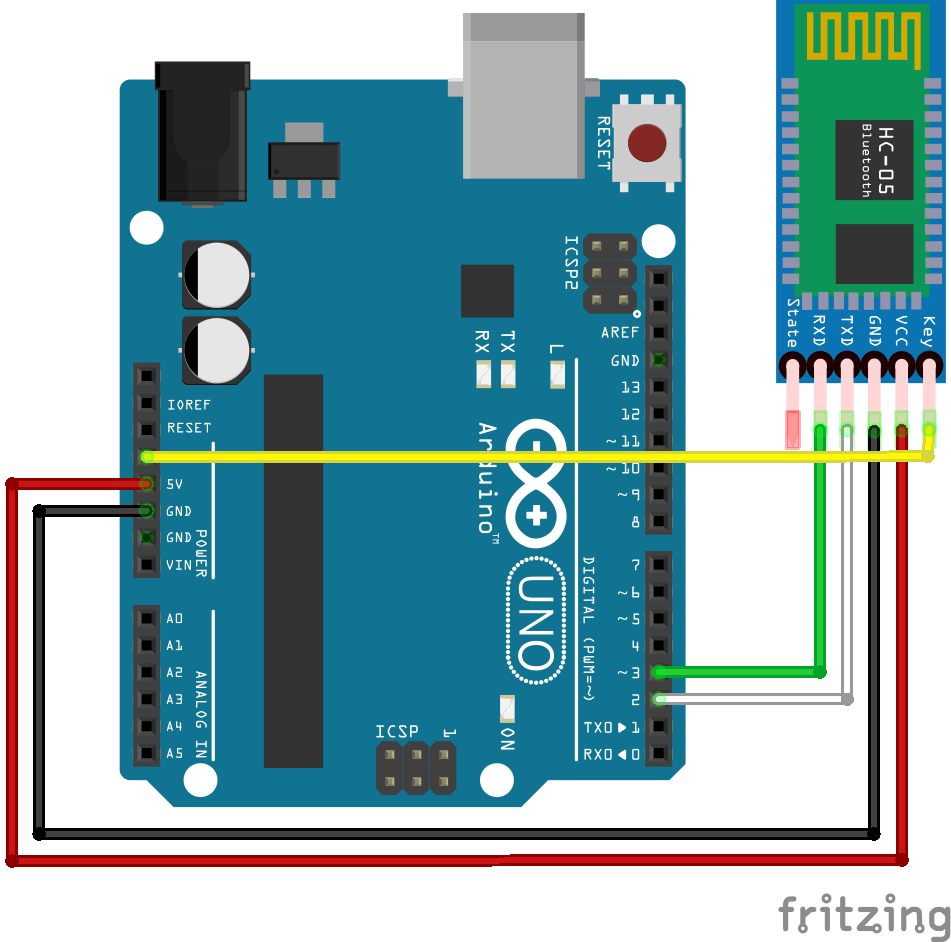
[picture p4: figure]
Tu Arduino se comunica con el módulo HC-05 • AranaCorp

Guía (https://github.com/impatrq/ojo_de_van_gogh/blob/develop/Docs/Carpeta_de_campo/Guias_md/Entorno%2520de%2520trabajo%2520de%2520Arduino%2520con%2520Bluetooth.md) (https://github.com/impatrq/ojo_de_van_gogh/blob/develop/Docs/Carpeta_de_campo/Guias_md/Entorno%2520de%2520trabajo%2520de%2520Arduino%2520con%2520Bluetooth.md)de (https://github.com/impatrq/ojo_de_van_gogh/blob/develop/Docs/Carpeta_de_campo/Guias_md/Entorno%2520de%2520trabajo%2520de%2520Arduino%2520con%2520Bluetooth.md) (https://github.com/impatrq/ojo_de_van_gogh/blob/develop/Docs/Carpeta_de_campo/Guias_md/Entorno%2520de%2520trabajo%2520de%2520Arduino%2520con%2520Bluetooth.md)como (https://github.com/impatrq/ojo_de_van_gogh/blob/develop/Docs/Carpeta_de_campo/Guias_md/Entorno%2520de%2520trabajo%2520de%2520Arduino%2520con%2520Bluetooth.md) (https://github.com/impatrq/ojo_de_van_gogh/blob/develop/Docs/Carpeta_de_campo/Guias_md/Entorno%2520de%2520trabajo%2520de%2520Arduino%2520con%2520Bluetooth.md)Establecer (https://github.com/impatrq/ojo_de_van_gogh/blob/develop/Docs/Carpeta_de_campo/Guias_md/Entorno%2520de%2520trabajo%2520de%2520Arduino%2520con%2520Bluetooth.md) (https://github.com/impatrq/ojo_de_van_gogh/blob/develop/Docs/Carpeta_de_campo/Guias_md/Entorno%2520de%2520trabajo%2520de%2520Arduino%2520con%2520Bluetooth.md)conexión (https://github.com/impatrq/ojo_de_van_gogh/blob/develop/Docs/Carpeta_de_campo/Guias_md/Entorno%2520de%2520trabajo%2520de%2520Arduino%2520con%2520Bluetooth.md) (https://github.com/impatrq/ojo_de_van_gogh/blob/develop/Docs/Carpeta_de_campo/Guias_md/Entorno%2520de%2520trabajo%2520de%2520Arduino%2520con%2520Bluetooth.md)entre (https://github.com/impatrq/ojo_de_van_gogh/blob/develop/Docs/Carpeta_de_campo/Guias_md/Entorno%2520de%2520trabajo%2520de%2520Arduino%2520con%2520Bluetooth.md) (https://github.com/impatrq/ojo_de_van_gogh/blob/develop/Docs/Carpeta_de_campo/Guias_md/Entorno%2520de%2520trabajo%2520de%2520Arduino%2520con%2520Bluetooth.md)BT (https://github.com/impatrq/ojo_de_van_gogh/blob/develop/Docs/Carpeta_de_campo/Guias_md/Entorno%2520de%2520trabajo%2520de%2520Arduino%2520con%2520Bluetooth.md)

Usando Arduino logramos hacer que funcionen los vibradores extraídos del Nokia usando la función Tone () y noTone () que te permite poner la frecuencia de vibración la cual va a variar según lo que se necesite

Guía (https://github.com/impatrq/ojo_de_van_gogh/blob/develop/Docs/Carpeta_de_campo/Guias_md/Sistema%2520de%2520Vibraci%25C3%25B3n.md) (https://github.com/impatrq/ojo_de_van_gogh/blob/develop/Docs/Carpeta_de_campo/Guias_md/Sistema%2520de%2520Vibraci%25C3%25B3n.md)de (https://github.com/impatrq/ojo_de_van_gogh/blob/develop/Docs/Carpeta_de_campo/Guias_md/Sistema%2520de%2520Vibraci%25C3%25B3n.md) (https://github.com/impatrq/ojo_de_van_gogh/blob/develop/Docs/Carpeta_de_campo/Guias_md/Sistema%2520de%2520Vibraci%25C3%25B3n.md)Sistema (https://github.com/impatrq/ojo_de_van_gogh/blob/develop/Docs/Carpeta_de_campo/Guias_md/Sistema%2520de%2520Vibraci%25C3%25B3n.md) (https://github.com/impatrq/ojo_de_van_gogh/blob/develop/Docs/Carpeta_de_campo/Guias_md/Sistema%2520de%2520Vibraci%25C3%25B3n.md)de (https://github.com/impatrq/ojo_de_van_gogh/blob/develop/Docs/Carpeta_de_campo/Guias_md/Sistema%2520de%2520Vibraci%25C3%25B3n.md) (https://github.com/impatrq/ojo_de_van_gogh/blob/develop/Docs/Carpeta_de_campo/Guias_md/Sistema%2520de%2520Vibraci%25C3%25B3n.md)vibración (https://github.com/impatrq/ojo_de_van_gogh/blob/develop/Docs/Carpeta_de_campo/Guias_md/Sistema%2520de%2520Vibraci%25C3%25B3n.md)

Como la Raspberry se maneja con JSON estuvimos aprendiendo a como procesar un string JSON en Arduino y poder hacer el intercambio de datos entre Raspberry y Arduino por BT. Nos dimos cuenta que para que se lean bien los datos hay que usar Serial.readString() ya que Serial.read() solo detecta que entra un char

JSON (acrónimo de JavaScript Object Notation, «notación de objeto de JavaScript») es un formato de texto sencillo para el intercambio de datos.

Empezamos a trabajar con el sensor cerebral conectado a un teléfono y logramos que cuando parpadee el usuario, el teléfono lo detecte, pero esto es una app y no nos permite tocarla mucho para usarla en nuestro Arduino, pero era a modo de primeros pasos. Usando un módulo bluetooth y comandándolo por AT tratamos de configurarlo insertando los siguientes datos

Baudrate = "576000"

BIND ADDR= "0081, f9,29eb31"

PSSW = "1234"

Con esta configuración no funciono ya que la password estaba mal puesta. Viendo la documentación nos dimos cuenta que la pass es 0000

PSSW CORRECTA ="0000"

Ya de esta forma pudimos conectar el Arduino con el HC-05 pero con el example que nos da el fabricante solo podemos medir nivel de atención y relajación. Tenemos que investigar como medir nivel de pestañeo. Sin embargo, hicimos una prueba donde se prenden leds de acuerdo a que tan concentrado está el usuario

Establecimos el entorno de trabajo en Google Visión IA que es usar la Nube de Google para, a través de un sistema de redes neuronales, obtener un análisis de lo que se ve en una foto. Para esto tuvimos que crear un proyecto en Google Cloud Services y habilitar la api de Google Visión AI. Una vez habilitado esto nos dan un archivo JSON que tiene nuestra API Key y la insertamos en la Raspberry usando

export GOOGLE_APPLICATION_CREDENTIALS=/home/pi/filename.json

Una vez seteada la Raspberry se usan los siguientes comandos para instalar las dependencias necesarias

python3 -m pip install --user pip

python3 -m pip install --user google-cloud-vision
python3 -m pip install --user Pillow python3 -m pip install --user picamera

Usamos este comando para sacar una foto

raspistill -o cam.jpg

Y este ejemplo para poder probar el análisis de la foto

python3 camera_vision_face.py

Nos devuelve este análisis donde la Raspberry se encargó de detectar las personas que aparecen en la foto en este caso Theo. Lo borroso de la foto se debe a que Theo tiene el celu que no enfoca, la definición en sí de la Pi Camera es bastante buena

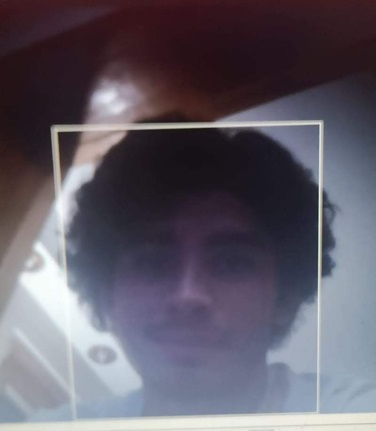
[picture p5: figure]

Ahora tenemos que ver cómo usar la Raspberry para conectarla al BT y además que todos estos programas que describimos antes estén funcionando en Loop y de forma automática cuando se prende la Raspberry.

Semana 22/03 - 29/03

Estuvimos viendo documentaciones y aparentemente para poder leer el valor de Blink Strength tenemos que escribir en el registro 0x16

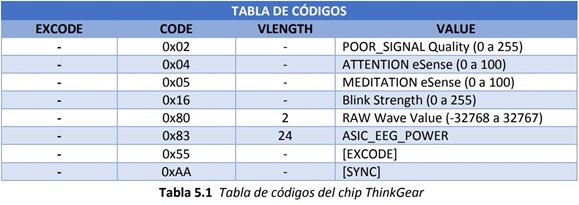
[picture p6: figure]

Se hicieron ejemplos con Arduino para empezar a leer los datos Json que se recibirán de la Raspberry. Se han hecho pruebas de como formar un Json y como obtener el valor de Json. Luego se probó mandar archivos String por BT, pero nos dimos cuenta que la función no permite mandar Strings por BT:

BTMaster.write()

Se ha visto varios videos o formas de intentar mandar el String por BT de otra forma, pero no se ha conseguido, entonces se empezó a investigar para pasar un String a un char Array. Se ha encontrado un ejemplo en el que muestra que la función:

str.toCharArray(charArray,buf)

Siendo str el String ingresado, charArray, la variable donde se guarda el charArray y buf la cantidad máxima a convertir de String en char Array.

Se ha tenido problemas con esta función ya que dependiendo del orden en el que se declaraba el String, funcionaba o no. Pero se ha logrado descubrir el error, creando 2 programas:

- Uno que simula el parpadeo, sacar foto y mandar el String Json por BT a través de un charArray
- El otro que recibe el char Array y lo convierte en un String, y obtiene el valor del Json de color y de acuerdo al color realiza una vibración

Sistema (https://github.com/impatrq/ojo_de_van_gogh/blob/develop/Docs/Carpeta_de_campo/Guias_md/Sistema%2520de%2520vibraciones%2520de%2520acuerdo%2520al%2520color.md) (https://github.com/impatrq/ojo_de_van_gogh/blob/develop/Docs/Carpeta_de_campo/Guias_md/Sistema%2520de%2520vibraciones%2520de%2520acuerdo%2520al%2520color.md)de (https://github.com/impatrq/ojo_de_van_gogh/blob/develop/Docs/Carpeta_de_campo/Guias_md/Sistema%2520de%2520vibraciones%2520de%2520acuerdo%2520al%2520color.md) (https://github.com/impatrq/ojo_de_van_gogh/blob/develop/Docs/Carpeta_de_campo/Guias_md/Sistema%2520de%2520vibraciones%2520de%2520acuerdo%2520al%2520color.md)vibraciones (https://github.com/impatrq/ojo_de_van_gogh/blob/develop/Docs/Carpeta_de_campo/Guias_md/Sistema%2520de%2520vibraciones%2520de%2520acuerdo%2520al%2520color.md) (https://github.com/impatrq/ojo_de_van_gogh/blob/develop/Docs/Carpeta_de_campo/Guias_md/Sistema%2520de%2520vibraciones%2520de%2520acuerdo%2520al%2520color.md)con (https://github.com/impatrq/ojo_de_van_gogh/blob/develop/Docs/Carpeta_de_campo/Guias_md/Sistema%2520de%2520vibraciones%2520de%2520acuerdo%2520al%2520color.md) (https://github.com/impatrq/ojo_de_van_gogh/blob/develop/Docs/Carpeta_de_campo/Guias_md/Sistema%2520de%2520vibraciones%2520de%2520acuerdo%2520al%2520color.md)Json (https://github.com/impatrq/ojo_de_van_gogh/blob/develop/Docs/Carpeta_de_campo/Guias_md/Sistema%2520de%2520vibraciones%2520de%2520acuerdo%2520al%2520color.md) (https://github.com/impatrq/ojo_de_van_gogh/blob/develop/Docs/Carpeta_de_campo/Guias_md/Sistema%2520de%2520vibraciones%2520de%2520acuerdo%2520al%2520color.md)y (https://github.com/impatrq/ojo_de_van_gogh/blob/develop/Docs/Carpeta_de_campo/Guias_md/Sistema%2520de%2520vibraciones%2520de%2520acuerdo%2520al%2520color.md) (https://github.com/impatrq/ojo_de_van_gogh/blob/develop/Docs/Carpeta_de_campo/Guias_md/Sistema%2520de%2520vibraciones%2520de%2520acuerdo%2520al%2520color.md)BT (https://github.com/impatrq/ojo_de_van_gogh/blob/develop/Docs/Carpeta_de_campo/Guias_md/Sistema%2520de%2520vibraciones%2520de%2520acuerdo%2520al%2520color.md)

Hemos realizado el logo para el proyecto:

Semana 29/03 al 05/04

Se crearon las piezas en 3D del cargador de pilas. Las piezas están diseñadas teniendo en cuenta las plaquetas que van a ir colocadas y están los agujeros para los respectivos cables.

Cargador parte 1

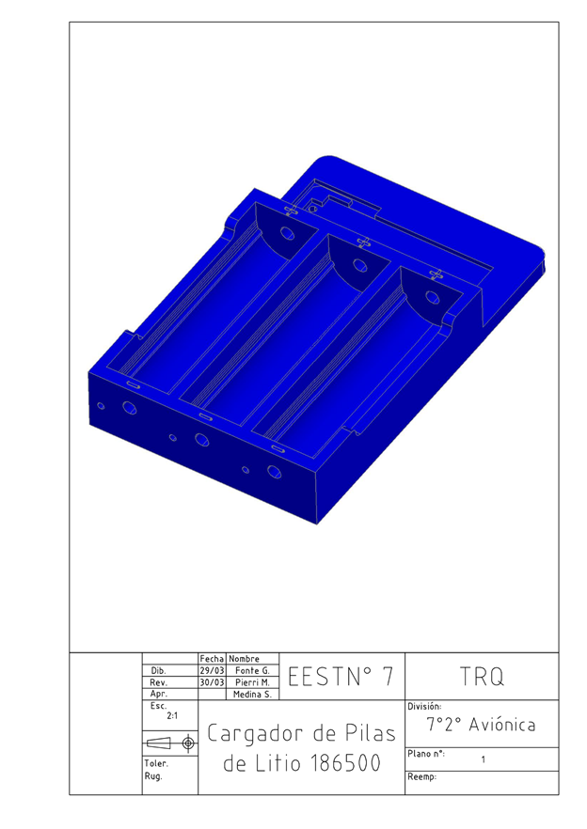
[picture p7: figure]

Cargador parte 2

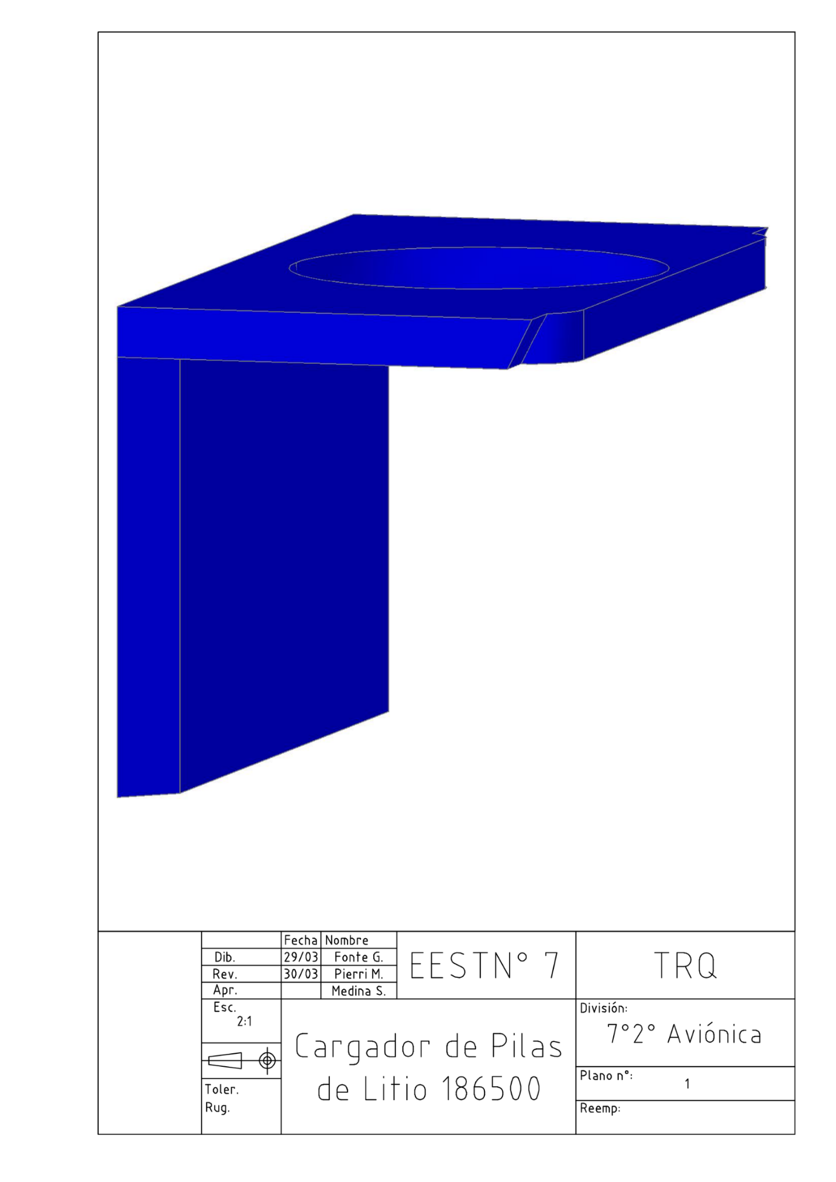
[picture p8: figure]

Cargador parte 3

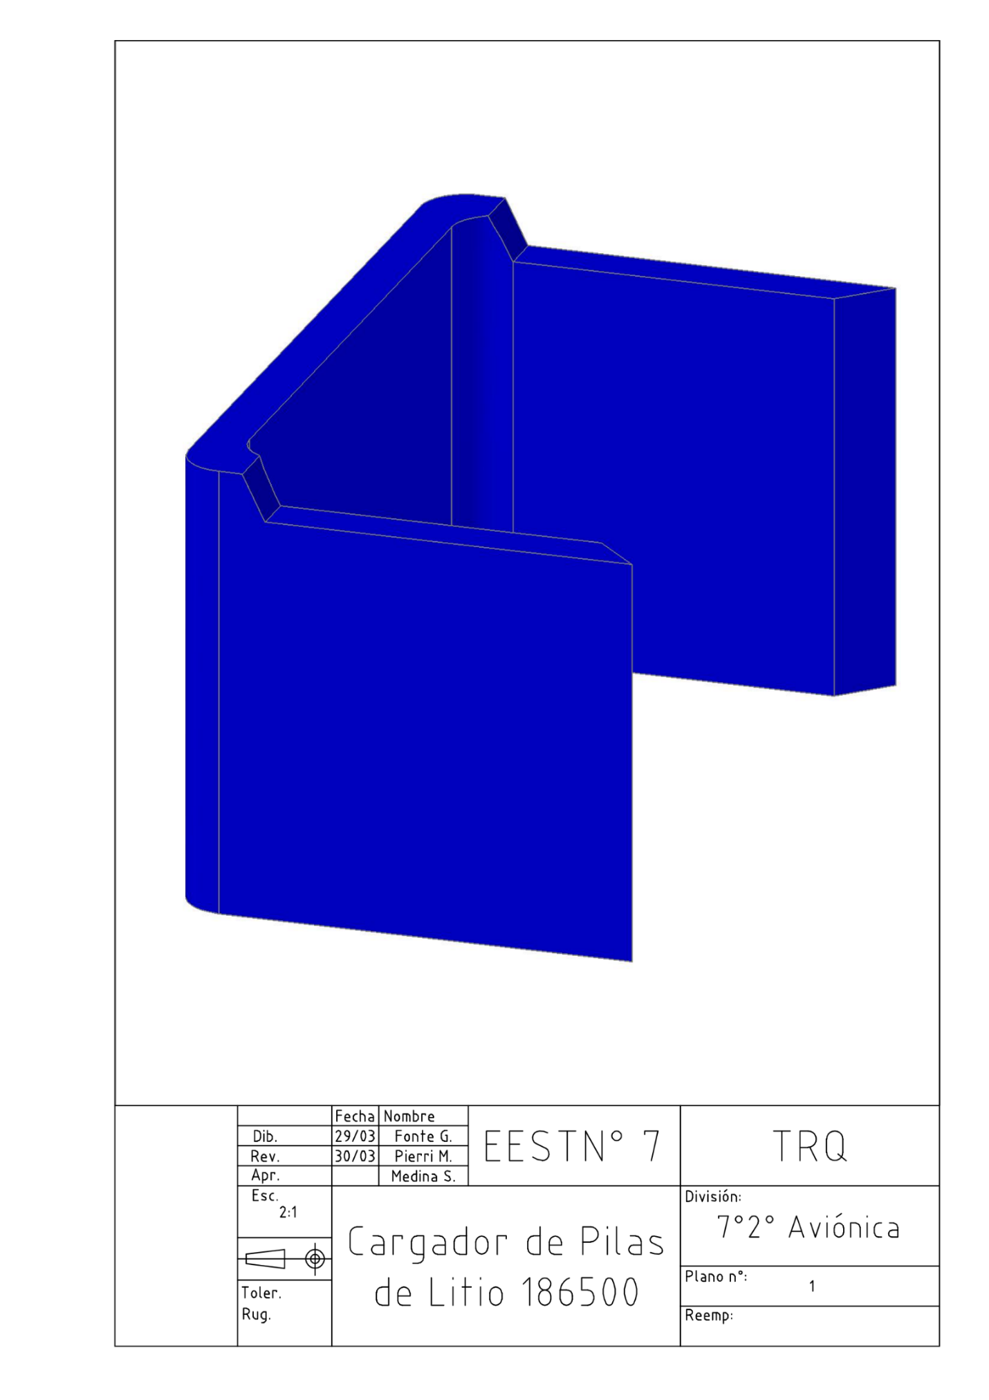
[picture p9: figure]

Analizamos el problema que creamos en el repositorio de Ojo de Van Gogh ya que nos mezclamos con el manejo de branches y mil problemas entonces decidimos crear repositorios por cada área de trabajo del proyecto y los archivos de documentación y publicidad manejarnos por drive. Los repos quedan de la siguiente manera:

- Mindwave
- ArduinoVibrador Raspberry
- Cargador de pilas

Ahora nos manejamos con ramas donde la versión final y estable del repo va a Máster y luego cada feature se desarrolla en una rama paralela. Luego de hacerle el testing a la misma y ver que no haya conflicto se hace un merge (se fusiona la rama con el máster y se cierra la rama)

Con respecto al mindwave decidimos poner en pausa el código del micro porque nos estábamos perdiendo con el tema del payload. Encontramos varios repos en GitHub con los códigos en Python donde al ejecutarlos te otorgan los datos. El plan es conectar por BT el mindwave a la computadora y correr el script. Una vez que el mismo esté listo

Nos estamos contactando con varias empresas preguntando sobre plaquetas flexibles para el sistema de vibración, aunque también se está evaluando la opción de utilizar los brazaletes porta celulares para correr. Se ha realizado el PCB del sistema ya que una empresa nos contactó y nos lo pidió para saber el tamaño y complejidad.

Semana 05/04 al 12/04

Hemos recibido las respuestas de las empresas por plaquetas flexibles y nos ha parecido muy elevados los costos por lo cual optamos por usar un brazalete para celulares de un tamaño de 18cm x 10 cm y se ha realizado el esquemático del circuito donde estará la Raspberry con la cámara, el Arduino Nano, el Bluetooth, dos pilas, un regulador y los vibradores.

Hemos calculado el consumo total del circuito para saber que tenemos que usar dos pilas de 3.7V ya que con una nos duraría poco tiempo, y por esto se ha investigado sobre Step Down, ya que tiene mejor rendimiento que un regulador, ya que se necesitan 5V de entrada en vez de los 7.4V que nos dan las dos pilas en serie.

También se ha realizado una librería para los colores en Arduino, y hemos encontrado el problema que si haces un archivo con la extensión: ".c " salta un error y se solucionó esto cambiando la extensión del archivo a ".cpp"

Se ha investigado sobre el mindwave y el funcionamiento de un programa y se ha conseguido que se detecte el parpadeo, pero también se detecta el parpadeo no forzado y para eso estamos viendo cómo solucionarlo.

Se ha conseguido que la Raspberry nos entregue el color en RGB con Json

Se ha comprado un dominio y estamos haciendo la página web a través de un localhost (XAMPP) y usando WordPress. Se ha elegido el tema de la página que es BlackootLite.

Semana 12/04 al 19/04

Se ha terminado el PCB de la placa

Montamos el host en 000webhost que nos ofrece 300 Mb de espacio y le instalamos WordPress. Tuvimos problemas con el dominio así que contactamos a soporte técnico de Hostinger y nos solucionaron el problema.

Clic aquí (https://ojodevangogh.tech/) (https://ojodevangogh.tech/)para entrar a nuestra pagina

Encontramos un módulo de Python que pasa de RGB a nombre de color y funciona, pero tienen sus limitaciones. El tema es que no da resultado a todos los RGB sino a los que son fáciles tales como 0,0,0 que da black, pero si le metemos algo como 65,23,19 ya se pierde.

Encontramos una alternativa basándonos en la página de un sensor de color que nos otorga Luis llamas

Sensor (https://www.luisllamas.es/arduino-sensor-color-rgb-tcs34725/) (https://www.luisllamas.es/arduino-sensor-color-rgb-tcs34725/)para (https://www.luisllamas.es/arduino-sensor-color-rgb-tcs34725/) (https://www.luisllamas.es/arduino-sensor-color-rgb-tcs34725/)Detectar (https://www.luisllamas.es/arduino-sensor-color-rgb-tcs34725/) (https://www.luisllamas.es/arduino-sensor-color-rgb-tcs34725/)colores (https://www.luisllamas.es/arduino-sensor-color-rgb-tcs34725/)

Acá muestra un sensor para detectar colores y en esta usan una librería que pasa los valores RGB a HSV que nos permite saber las distintas tonalidades de un color ya que distingue de rojo oscuro y rojo claro y nos permite tomar los dos como rojo. Esta librería la pasamos a Python y gracias a esto ya poseemos 12 colores identificables

Hemos realizado la librería para la vibración de los colores y para esto hemos creado una tabla para determinar la vibración de cada color:

Lista de colores para vibración

- El número 0 representa 0.25 segundos de duración de vibración
- El número 1 representa 1 segundo de duración de vibración
- Entre cada número hay 0.25 segundos de pausa

Código de Vibración | Colores
0000 | Blanco
0001 | Rojo
0010 | Marrón
0011 | Naranja
0100 | Amarillo
0101 | Verde
0110 | Cian
0111 | Azul
1000 | Violeta
1001 | Rosa
1010 | Gris
1011 | -
1100 | -
1101 | -
1110 | -
1111 | Negro

La página web se nos cayó. Nos suspendieron la página porque aparentemente superamos el límite de visitas al entrar a verla y nos dicen que si no pagamos en 7 días nos la borran.

Nos comunicamos con webhost a ver si hay alguna alternativa, pero no nos contestan así que no nos queda otra que pagar y mudarnos a Hostinger

Logo 3D

Se ha hecho el logo en formato 3D para después agregarlo como marca en la caja que tengamos.

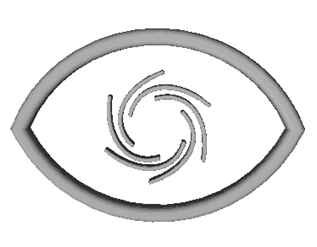
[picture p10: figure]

Semana 19/04 al 25/04
Pagamos la migración de nuestra página a Hostinger que nos salió 10 dólares. Tenemos que esperar 48 hs a que nos digan sí salió todo bien y no perdimos la página.

Recuperamos la página y esta todo en orden, aunque se nos desconfiguró el dominio y tenemos que cambiarlo así responde a ojodevangogh.tech . Eso sí, no podemos entrar al panel de WordPress por alguna razón.

Nos comunicamos con Hostinger y después de unos largos idas y vueltas de email mudamos completamente la página ya no tenemos nada en webhost está todo en Hostinger y funciona todo. Habilitamos la certificación SSL así que nuestra página es segura y ya tenemos acceso al panel de WordPress.

Tenemos un problema en el responsive desing que hace que desaparezcan los botones de la página cuando usamos una versión mobile y no sabemos que hacer

Semana 25/04 al 3/5

Vimos que no había manera de solucionar el responsive design más que pagar el upgrade del theme de WordPress a premium que son 40 dólares así que decidimos cambiar de tema de WordPress.

Empezamos la búsqueda y encontramos uno llamado Astrid que está muy bueno visualmente y tiene mucha opción de personalización. Lastimosamente no podíamos cambiarle el fondo blanco así que para que no queme tanto le colocamos letra Arial que es más gruesa y llama la atención.

Le instalamos un plugin a la página para que aparezcan botones que vinculen la página con Instagram, LinkedIn llamado UltimateShare.

Creamos una página de Instagram para empezar a subir cosas y ya grabamos unos videos de como la Raspberry reconoce colores y como a través de un color seleccionado funcionan los vibradores

Para un mejor orden creamos un repositorio nuevo donde metimos todas las cosas de los pequeños repos a través de git flow que permite ordenar todo en feature.

Para armar cosas lindas para redes sociales hicimos que la plaqueta tenga todos los micros y cosas con modelos 3D así verlos con el visor 3D de KiCAD

Semana 03/05 al 11/05

Se hizo una introducción para el video en After Fx, se le puso música de fondo y se subió a Instagram y a la página web el primer video mostrando como se reconoce el color con la cámara de la Raspberry

También se definió el modelo para hacer la tapa del cargador de pila y se empezó a hacerla.

Se agregó un plugin para que la pagina cargue más rápido y se corrigió el logo para que no sea de fondo blanco y pueda verse.

Semana 11/05 al 18/05

Se empezó a intentar conectar la Raspberry con el sensor cerebral y se configuro esta para que trabaje por Remote

Agregamos con gtts para que se pueda escuchar el color y lo probamos con un parlante y anduvo. Para traducir el texto color a voz se creó una nueva función que envía archivo txt que los recibe el gtts y los reproduce en un parlante

Para la PRIMER ENTREVISTA DE RADIO, se realizó una tarjeta publicitaria que se subió a Instagram y como se
escucho bajo, se editó el audio grabado y se preparó para subirlo a IGTV y quedamos en que cuando la situación del país lo permita, nos volveremos a juntar para contar los nuevos avances.

Se daño el disco de la computadora y perdimos lo que teníamos hecho de la tapa y no se había subido a git.

Semana 18/05 al 25/05

Se pudo conectar el sensor cerebral con la Raspberry, pero no lee el payload del Mindwave y estamos con ese problema que no sabemos cómo resolverlo

Se hizo un Backup de la página web porque se nos vencía el mes de Hostinger, pero debido a un error que tuvieron nos regalaron un mes y ya elegimos que para el mes próximo vamos a cambiar al host de Sitio Hispano que nos saldría $860 el año ya que no se puede pagar por mes

Estuvimos pensando y se nos ocurrió que nuestra página tiene que tener para que los ciegos la puedan leer, entonces agregamos el Plugin Responsive Voice que permite a través de un botón reproducir el contenido de cada página.

Se edito y subió el IGTV de la nota de radio y también subimos el link de la página que hizo la radio FM106.5 sobre esta nota.

Se terminó la tapa y se empezó a realizar el encastre en la caja.

Se crearon archivos txt para el gtts para optimizar los tiempos de respuesta cuando se reproducen los colores, ya que lee los archivos creados en vez de crearlos y después leerlo.

Semana 25/05 al 1/06

Se logró la comunicación entre el Arduino y la Raspberry y creamos 2 librerías una para detectar colores y otra para crear un JSON. Esto se hizo para ordenar el código. A la librería de detectar colores también se le incorporó los audios para reproducir el color.

Se investigó como hacer que cada vez que la Raspberry se enciende empiece a correr el script automáticamente sin ponerle el comando utilizando Crontab.

Script (https://github.com/impatrq/ojo_de_van_gogh/blob/develop/Docs/Carpeta_de_campo/Guias_md/Correr%2520script%2520cada%2520vez%2520que%2520se%2520prenda%2520la%252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) (https://github.com/impatrq/ojo_de_van_gogh/blob/develop/Docs/Carpeta_de_campo/Guias_md/Correr%2520script%2520cada%2520vez%2520que%2520se%2520prenda%2520la%252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)para (https://github.com/impatrq/ojo_de_van_gogh/blob/develop/Docs/Carpeta_de_campo/Guias_md/Correr%2520script%2520cada%2520vez%2520que%2520se%2520prenda%2520la%252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) (https://github.com/impatrq/ojo_de_van_gogh/blob/develop/Docs/Carpeta_de_campo/Guias_md/Correr%2520script%2520cada%2520vez%2520que%2520se%2520prenda%2520la%252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)automatizar (https://github.com/impatrq/ojo_de_van_gogh/blob/develop/Docs/Carpeta_de_campo/Guias_md/Correr%2520script%2520cada%2520vez%2520que%2520se%2520prenda%2520la%252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) (https://github.com/impatrq/ojo_de_van_gogh/blob/develop/Docs/Carpeta_de_campo/Guias_md/Correr%2520script%2520cada%2520vez%2520que%2520se%2520prenda%2520la%252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)inicio (https://github.com/impatrq/ojo_de_van_gogh/blob/develop/Docs/Carpeta_de_campo/Guias_md/Correr%2520script%2520cada%2520vez%2520que%2520se%2520prenda%2520la%252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)

Se ha logrado pasar las fotos a formato base64 para reducir tiempos de espera y se logró una optimización. Antes tardaba 24 segs y ahora tarda entre 16 y 20 segs, siendo un factor clave la luz ambiente, ya que si hay poca luz tarda más.

Se ha investigado e implementado en la página web sobre plugins de accesibilidad, se han probado varios pero el que más herramientas nos proporciona es UserWay, Este plugin tiene varias herramientas

- Permite 3 niveles de lector de pantalla (medio, rápido y despacio).
- Navegar por teclado (accesibilidad para ciego y poca motriz)
- Cambiar los contrastes de fondo (gris, invertido, oscuro y claro)
- Permite resaltar enlaces
- Aumentar el tamaño y el espaciado del texto y también del cursor
- Detener animaciones
- Cambiar la letra para la gente que padece dislexia
- Aumentar el cursor y tener una guía de lectura
- Y por último ofrece resetear todas las opciones

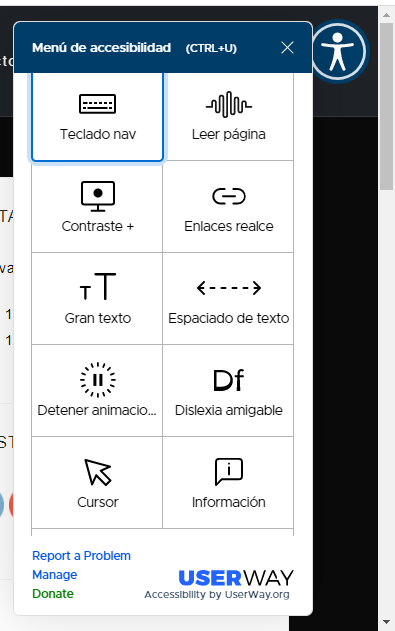
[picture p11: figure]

Se ha avanzado con el modelado 3D de la caja que contiene el proyecto, modificando los espacios para las pilas ya que no iban a entrar con el que tenía y se avanzó con el encastre de la tapa con la caja agregando los agujeros en la misma.

Semana del 1/06 al 8/06

Se editó y musicalizó un segundo video para subir a las redes, el cual mostrara como al reconocer un color empezaría a reproducirse un sonido/vibración.

Se subió a ig historias de quienes somos y una breve descripción del proyecto, dejando estas mismas como destacadas y se aumentó 16 seguidores.

Se hicieron varias pruebas para empezar a reconocer texto y con el código que ofrece la api no lográbamos poder reproducir el texto, entonces hemos buscado otro código el cual nos permitió reproducir el texto que reconoció de la imagen que le cargamos a la Raspberry

Se han buscado diferentes librerías para hacer una lectura de OCR más rápida pero no se encontró, y viendo videos y características, hemos decidido pasar de la Raspberry Pi Zero w a la Raspberry Pi 3 y hemos tenido las siguientes mejoras:

- Reconocimiento de colores en 5 segs
- Reconocimiento de texto entre 7 y 11 segs
- Reconocimiento de objetos en 10 segs

Se hizo un código para reconocer objetos obteniendo el objeto con mayor seguridad. Se ha agregado para que el objeto sea traducido ya que la librería da el resultado en inglés. Hemos aprovechado esto para darle una herramienta más al proyecto y permitir que cuando una persona quiera leer texto que no sea español, sea traducido y se reproduzca por el auricular.

Se ha instalado el plugin Yoast que sirve para saber qué características faltan para mejorar el SEO de la página (optimización de los buscadores). Luego se ha procedido a cambiar la página de inicio agregando información y cambiando títulos de acuerdo a la palabra clave ingresada "ciego ven colores".

Debido a que la actividad cerebral de cada persona es distinta y no se puede tomar una medida precisa para usar cuando se parpadea, hemos empezado a investigar sobre desviación estándar. Para ver el grafico de la desviación estándar se investigó sobre la librería pandas, pero después vimos que no era necesario y teníamos problemas con el ajuste de escala.

Se hizo un graficador de las ondas cerebrales a través de Arduino usando Matplotlib y hemos visto que la desviación estándar con 2 parpadeos no es tan estable ya que varía entre 50 y 60 pero cuando la persona parpadea 3 veces es mucho más estable dando unos valores de 80.

Se termino con el diseño 3D de la caja y tapa agregando un encastre para que entre a presión, quedando lista para su impresión.

Tapa de la caja

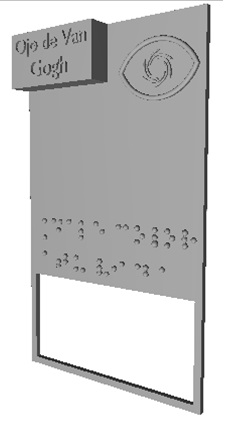
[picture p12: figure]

Caja por dentro

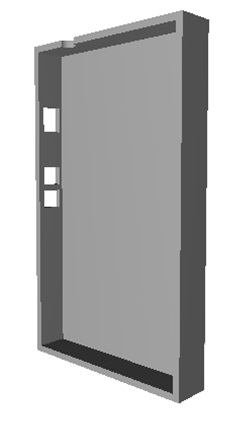
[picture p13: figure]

Semana del 8/06 al 15/06

Se crearon librerías para tener el código más prolijo.

- Librería de reconocimiento de texto tanto en español como en otro idioma, ya que tiene la opción de que cuando se reconozca que es otro idioma sea traducido
- Librería de reconocimiento de objetos, dando el contenido en español.

Se agrego para que se pueda reconocer la ubicación de dichos objetos detectados y limitando a que te diga solo los que la api detecta con una buena precisión (score).

Se ha mejorado la página "El proyecto", basándonos en las características de mejorar la legibilidad y algunas cuestiones de SEO.

Semana del 15/06 al 22/06

Se grabo un video mostrando el reconocimiento de colores, objetos y leyendo un texto. Luego se agregaron efectos especiales

Se hizo una publicación para IG por la entrevista que tuvimos el viernes, y se editó el video, musicalizo y se subió a IGTV. Nos hemos contactado con ASAC y estamos esperando la respuesta.

Mudamos la página a un nuevo host (SitioHispano) que nos salió 860 $ el año

Se ha detectado cuando entra información del Mindwave para tomar el valor promedio de la persona en los primeros segundos.

Se adapto para que se reconozcan los 2 colores que más ocupan en la foto y luego ordenarlo para que primero este el que mejor se reconoció (score más alto).

Se actualizo la librería de objetos, agregándole la ubicación del mismo

Semana del 22/06 al 29/06

Se hizo una librería para el código de Mindwave para que quede más ordenado.

Se incluyo en la librería de RGB para que se pueda reconocer 2 colores si la diferencia de score es menor a 0.10

En la página web, agregamos las sliders en la paginas de noticias para que sea más cómodo y lindo.

Se hizo el anuncio para la radio 99.3 FM que sale el viernes y se ha publicado con la edición de musicalización el tercer video mostrando el reconocimiento de colores, texto y objetos

Se nos ocurrió para mejorar la calidad del reconocimiento de colores, crear una tabla de Excel y copiar los 140 colores que nos da la página de Wikipedia con sus RGB y sus nombres. Luego exportamos esa tabla a pandas y hemos agregado 2 condiciones para los colores negro y blanco.

Semana del 29/06 al 06/07

Se subió el IGTV de la entrevista de la radio y también se ha subido a YouTube y a la página web.

Se agrego dos condiciones de blanco y negro para descartar más rápido y si no se cumplen que recorran el código a través de búsqueda binaria en Rojo, haciendo que el código sea más rápido.

Hemos puesto que, si no se encuentra algún color en la tabla, se agregue ese valor a la misma. Luego será revisado por alguno de los integrantes, clasificándolo y quedando la tabla ya actualizada.

También hemos probado algunas fotos y clasificando los colores que no se han reconocido.

Semana del 06/07 al 14/07

Se incluyo en la página web un mensaje de bienvenida y también un nuevo símbolo cuando las paginas están cargándose.

Se ha contactado nuevamente con ASAC y MasScience y nos prometieron publicar pronto un artículo nuestro en su página. Se ha mandado mails tanto a medios nacionales como radios.

Se normalizaron todos los códigos haciendo que todos queden con la misma estructura de pedir el dato a obtener: color, texto u objeto.

Se ha creado una clase de búsqueda binaria y ordenado el main. Se creo una nueva clase llamada Google Vision Engine. En esta clase se han creados los métodos de:

- Pedir color
- Elegir ese color(query)
- Leer texto y reproducirlo
- Reconocer objetos y su ubicación

Nos hemos dado cuenta de que muchas variables y partes de código que no se usaban y las hemos borrado. Hemos agregado para que cada valor nuevo en la tabla, se reorganice de menor a mayor y se actualicen los id

Se preparo la encuesta en Google forms para saber que piensan las personas sobre el proyecto.

Semana del 14/07 al 21/07

Se ha realizado nuevamente el PCB, ya que hemos agregado el switch de 4 posiciones para que la persona elija una función del proyecto. También se ha reemplazado las pilas de litio y regulador de tensión y pusimos una entrada para un cargador portátil común.

Placa Terminada

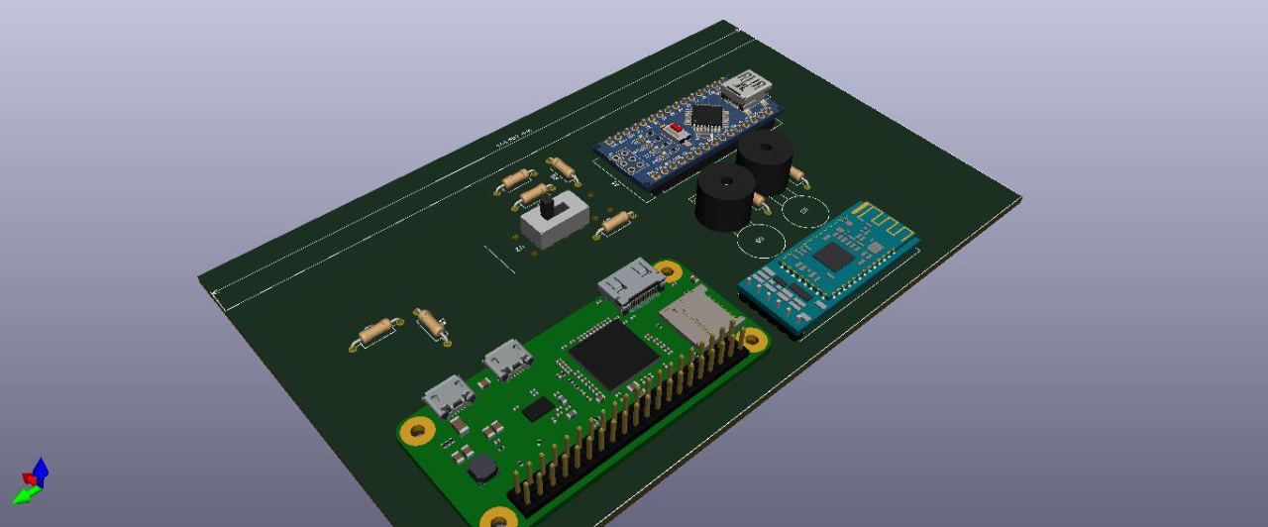
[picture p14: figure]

PCB Terminado

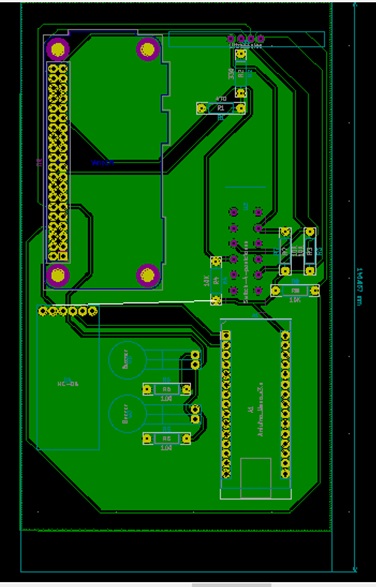
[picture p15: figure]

Esquemático Terminado

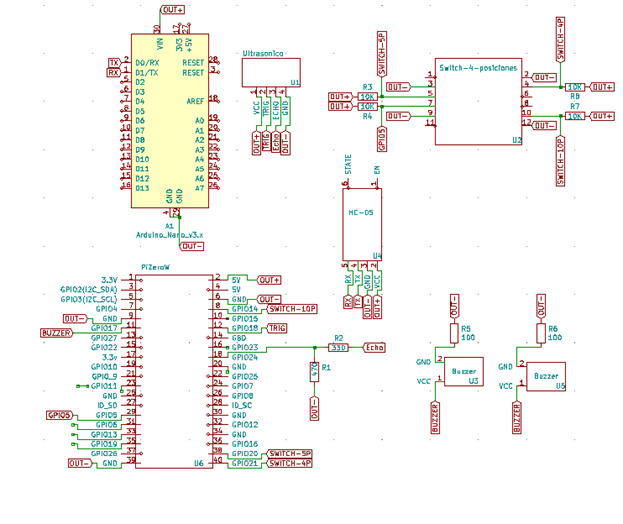
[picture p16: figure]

Se ha investigado para agregar que se corrijan las palabras cuando se las reconoce mal, pero con la librería Textblob era muy irregular y decidimos no usarlo.

Se paso el código de vibración, realizado en Arduino a Python para controlar el buzzer con la Raspberry. Esto se realizó ya que, si quisiéramos que el Arduino realice las vibraciones, se pierde tiempo para captar la señal que proviene del Mindwave. También se creó una función para que se pase de texto a audio

Se realizo la encuesta y hemos sacado buenas conclusiones sobre los datos obtenidos a través de las respuestas.

Semana del 21/07 al 28/07

Semana de descanso por receso escolar de invierno.

Semana del 28/07 al 04/08

Hemos investigado sobre lo que sería nuestro cliente ideal y tareas que quiera realizar, observando los beneficios y miedos o frustraciones de realizar dicha tarea. Una vez realizado esto, hemos planteado sobre las situaciones que le dan alegría y tristeza al cliente y que ofrecemos nosotros como producto y servicio.

Vamos a empezar a realizar entrevistas a personas con ceguera y hemos planteado como tienen que realizarse, lo que no hay que hacer y recomendaciones.

Hemos encontrado una tabla con 865 colores con sus nombres, valores hexadecimales y valores R, G, B e hicimos un código con dicha tabla buscando el color en la tabla que tenga menos diferencia con el color buscado.

Nos ha contactado la página de MasScience para decirnos que publicaron en su página un artículo sobre nuestro proyecto.

Clic aquí (https://www.masscience.com/2020/07/21/proyecto-ojo-de-van-gogh/) para ver el artículo del proyecto

Semana del 04/08 al 11/08

Se ha creado el método de audio y se agregó a la clase principal llamada Google Vision Engine, que es la clase que contiene todos los métodos. Una vez agregado la clase de audio se ha usado en los métodos de texto, objetos y color, para que se reproduzca por un parlante, el parámetro que se pida.

También nos hemos contactado con algunas personas que padecen ceguera para poder hacerles una entrevista y verificar cuáles son los problemas principales de estas personas en el día a día, y con esto nos han confirmado lo siguiente:

- Ellos se frustran no tener un sentido asociado al color y se preguntan que es, y al vivir en un mundo que se ve tienen que saber cómo vestirse, pero para ellos es lo mismo la combinación de colores. También buscan relacionar los colores con objetos, por ejemplo, que el rojo es del fuego
- Les molesta cuando las situaciones no tienen audios descriptivos. Y para cuando tienen que ir a comprar necesitan alguien que les diga cuanto sale y cuando es la fecha de vencimiento
- El reconocimiento de objetos para ellos es muy importante, ya que no pueden saber que hay cuando les mandan una foto, y si quieren ir a comprar necesitan de alguna persona para saber dónde está lo que ellos buscan.

Semana del 11/08 al 01/09

Semanas para rendir exámenes y entrega de trabajos prácticos. Hemos hablado de los pasos a seguir del proyecto:

- Armar guion y video para presentar el proyecto
- Hacer un diagrama de arquitecturas para organizar el código.

Semana del 1/09 al 8/09

Luego de haber hablado con el profesor durante varias semanas de como seguir y que mejoras tendríamos que hacer, hemos empezado por reorganizar el código. Para eso hemos armado un diagrama de arquitecturas definiendo todas las clases padres e hijas

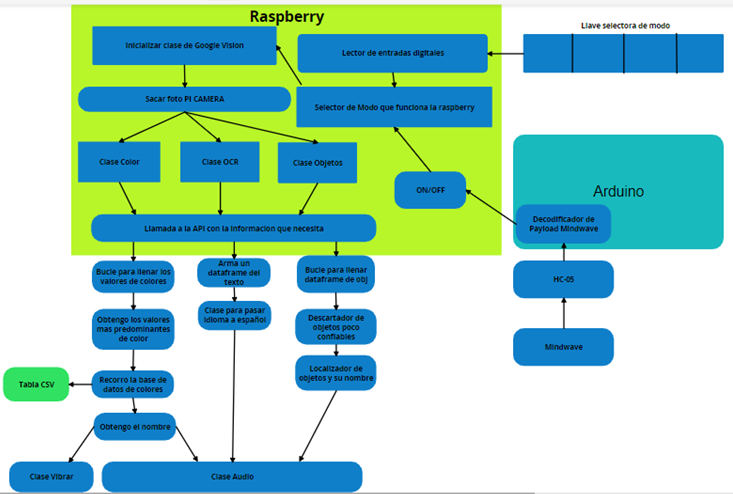
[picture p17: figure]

Hemos traducido el dataset de 860 colores para evitar traducirlo y hacer que el código sea más rápido

Semana del 8/09 al 15/09

Hemos realizado el refactoring de la clase de colores y un conteiner de Docker para poder hacer un despliegue a producción.

Hemos empezado a investigar sobre cómo se arma un video para poder presentar nuestro proyecto y hemos planteado los puntos principales que tiene que tener este.

Semana del 15/09 al 22/09

Hemos realizado el refactoring de la clase de objetos y de la clase de texto, que heredan de la clase Google Vision Engine, que tiene como parámetros el cliente y la imagen que se saca con la cámara de la Raspberry. También se empezó a armar el guion.

Semana del 22/09 al 29/09

Hemos realizado el refactoring de la clase de audio que es la que se encarga de pasar de texto a audio y reproducirlo. A esta clase se le pasa un parámetro que puede ser: los colores, los objetos o el texto y lo reproduce por audio.

También se hizo el refactoring de la clase que se encarga de realizar una vibración para el color. A esta clase se le pasa como parámetro el nombre del color que se reconoció y de acuerdo a la tabla de vibración se hará la vibración.

Se ha terminado de armar el guion para el video, en el cual se detallan que tiene que durar entre 2 y 3 min, y hay 2 voces en off que irán explicando la problemática que tienen las personas con ceguera y cuál es la solución que ofrecemos nosotros, mostrando los videos que hemos realizado donde se puede observar el reconocimiento de objetos, lectura de texto y reconocimiento de color con otro video que muestra cómo será la vibración de un determinado color.

Semana del 29/09 al 06/10

Hemos realizado el main.py usando todas las clases que ya armamos las semanas pasadas, y hemos puesto para que si se detecta un parpadeo dependiendo de lo que se pida se obtenga ese parámetro.

Para probar el funcionamiento de las clases y el main.py hemos cargado las siguientes imágenes:

- Para reconocer objetos hemos usado como ejemplo, la siguiente imagen:

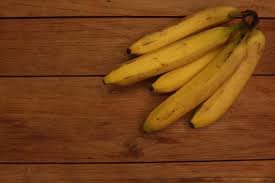
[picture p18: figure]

El resultado fue el siguiente:

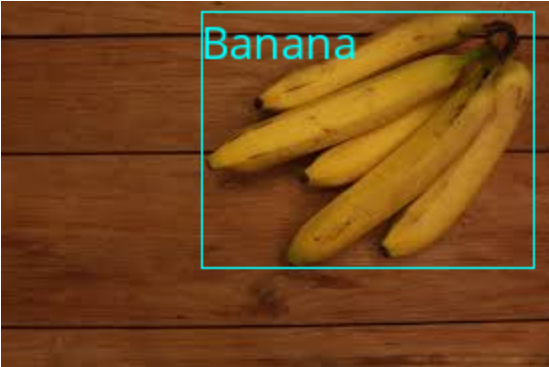
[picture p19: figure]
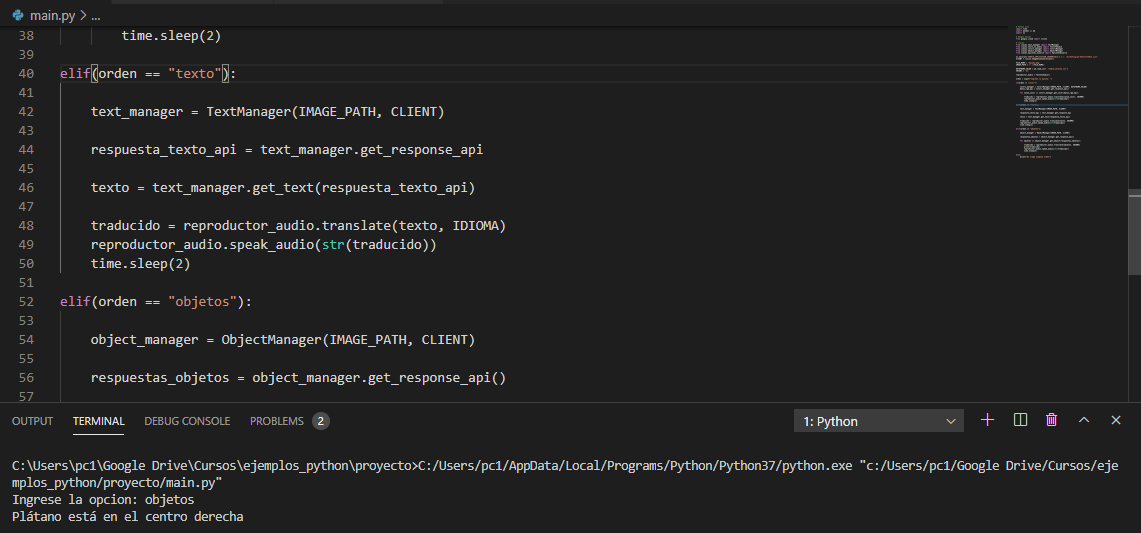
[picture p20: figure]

- Para reconocer el color hemos usado como ejemplo, la siguiente imagen:

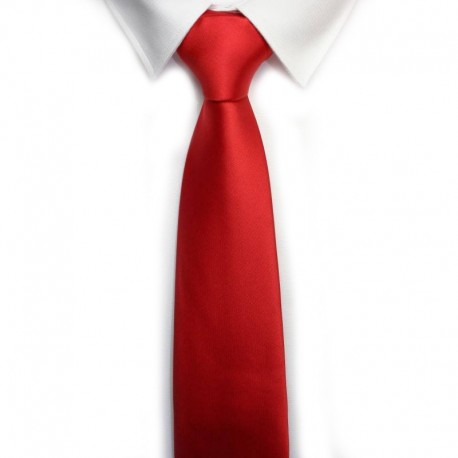
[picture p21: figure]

El resultado fue el siguiente:

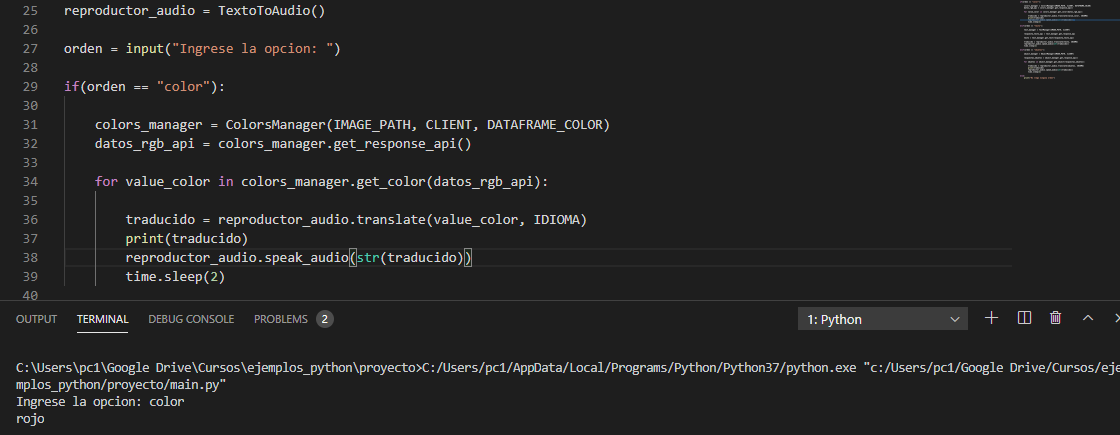
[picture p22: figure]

- Para reconocer el texto hemos usado como ejemplo, la siguiente imagen:

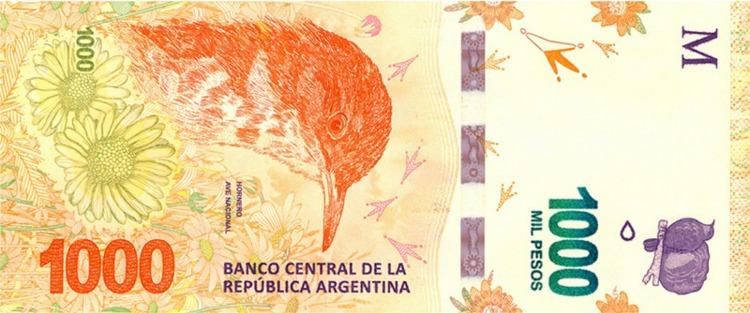
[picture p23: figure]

El resultado fue el siguiente:

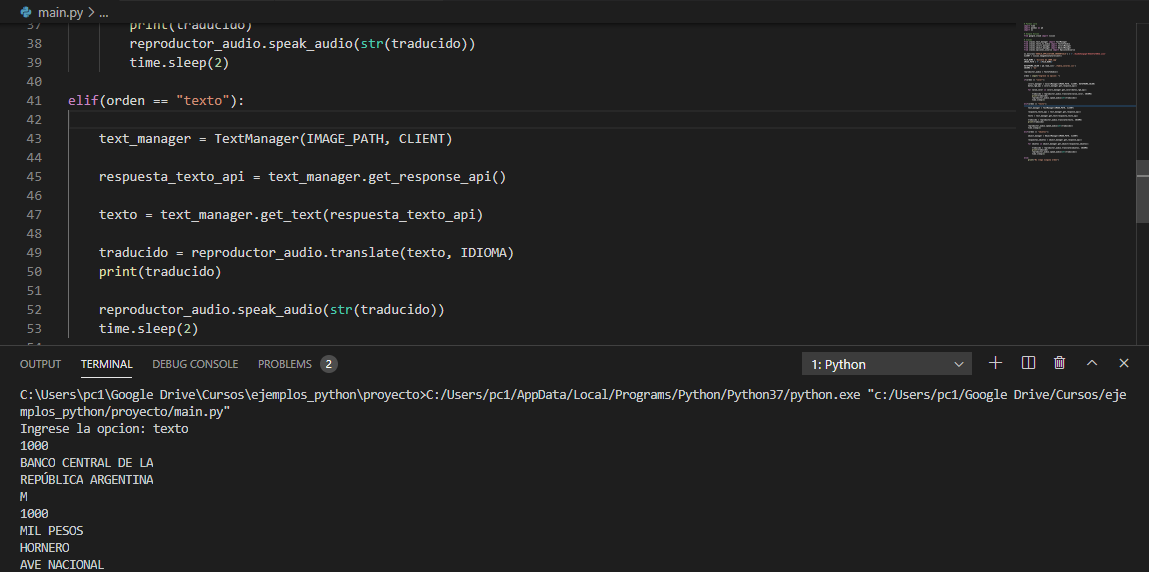
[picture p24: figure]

Hemos ordenado las carpetas de GitHub y realizado los distintos Readme para saber de qué se trata cada carpeta y se empezó a probar una plataforma, Animaker, para realizar la animación que irá acompañada del guion armado.

Prueba de la animación para el video

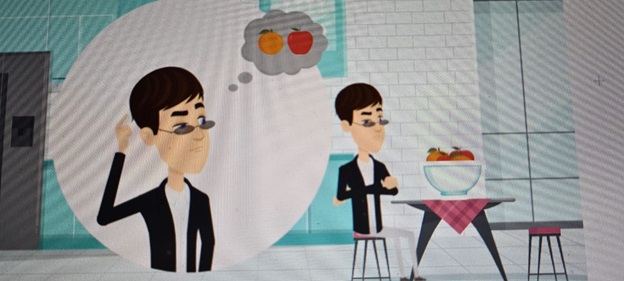
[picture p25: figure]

Semana del 06/10 al 13/10

Hemos empezado a crear columnas con los nombres de los colores principales para pasar a la función de vibrar, mientras que por audio saldrá el nombre completo, por ejemplo: rojo será para la vibración mientras que por audio saldrá rojo morado.

Se ha grabado el video para presentar el proyecto y se empezó a realizar la animación para mostrar la problemática del ciego y la solución que ofrecemos con el proyecto. También se ha realizado el informe descriptivo del proyecto.

Semana del 13/10 al 20/10

Hemos terminado el video animado para presentar en las ONIET y tambien corregimos algunos errores que habia en las clases del codigo y en el main.py

Semana del 20/10 al 03/11

Nos presentamos en la categoría Prototipos III en las ONIET y hemos conseguido el Primer Puesto.

Semana del 03/11 al 10/11

Hemos agregado la seccion “Documentación” en nuestra pagina web, en donde está el informe descriptivo del proyecto en el cual se pueden observar algunas caracteristicas tecnicas del código de programacion y del proyecto en general. Ademas hemos agregado un Popup para que las personas que entren a nuestra pagina sepan que van a encontrar en cada sección de la misma

También hemos hecho la pagina de Notion para la exposición del proyecto. En esta se explica da una breve descripción, dejando para mas información nuestras redes sociales y página web.

Semana del 10/11 al 17/11

Hemos hecho la parte de Estructura para la carpeta técnica del proyecto, en a cual se muestran las partes del proyecto realizadas en 3D tanto en perspectiva como sus vistas. También hemos realizado la parte de Electrónica en la que se detalla los esquematicos y PCB’s de la placa del proyecto, el programa usado y especificaciones técnicas.

Semana del 17/11 al 24/11

Hemos realizado la parte de Protocolos de comunicación del Mindwave(sensor cerebral), del Bluetooth y UART para el Arduino.

Se ha realizado la explicación de cada Microcontrolador utilizado y del BCI y sus diferentes tipos para poder entender lo que es el Mindwave.

Semana del 24/11 al 01/12

Se ha realizado la parte de Anexo detallando la Bibliografía utilizada y de Investigaciones realizadas sobre proyectos anteriores y de entrevistas que hemos tenido con distintas personas con discapacidad visual y cuales son sus dificultades en el día a día y cuales eran las recomendaciones que nos daban sobre el proyecto.

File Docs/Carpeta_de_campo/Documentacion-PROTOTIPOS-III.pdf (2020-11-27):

# Proyecto: “Ojo de Van Gogh”

Escuela: E.E.S.T N°7 “T.R.Q

Curso: 7mo 2

da Aviónica

Año: 2020

Link a la página web: ojodevangogh.tech


1 Para ver nuestras redes sociales buscar ojodevangogh.tech en Instagram 2 Para ver nuestra web page colocar el siguiente link ojodevangogh.tech

Integrantes:

- CARDINAL, Facundo Julián – DNI 44.051.731 – 7
mo 2

da Aviónica
- CARRO, Nahuel Agustín – DNI 43.660.810 – 7
mo 2

da Aviónica
- FONTE, Gonzalo Juan – DNI 43.173.573 – 7
mo 2

da Aviónica
- PIERRI, Matias Gabriel – DNI 44.128.118 – 7
mo 2

da Aviónica
- VILARDO, Theo – DNI 43.245.429 – 7
mo 2

da Aviónica
- VITTORE, Tobías – DNI 42.680.475 – 7
mo 2

da Aviónica

Tutores:

- MEDINA, Sergio
- BIANCO, Carlos

Fecha de inicio:

- 1

ro de marzo de 2020

Esfuerzo del proyecto:

- 24 horas semanales repartidas entre 6 personas
- 670 horas de trabajo en total
- 28 semanas de trabajo
- Tareas abarcadas:
- Investigación de problemática
- Desarrollo del producto
- Difusión y establecimiento en redes sociales

1
- Creación de web page²

Distinciones:

- Nota científica en “MasScience” ONG España
- Nota periodística en “Inquietudes de Sur”
- Entrevista de radio en “Crecer FM 106.5”
- Entrevista de radio en “Fan FM 103.9”
- Entrevista de radio en “Del Este FM 99.3”
- Medalla de Oro en Prototipos III en las ONIET

Nuestro repositorio GitHub:

- https://github.com/impatrq/ojo_de_van_gogh

## Índice:

### 1. Introducción

### 2. Software

### 3. Sistema Embebido

### 4. Electrónica

### 5. Estructura

### 6. Anexo


### 1. Introducción

1.1. Objetivo:

El objetivo de este proyecto es brindar a la gente con discapacidad visual un dispositivo electrónico capaz de ayudarlo a leer textos, reconocer objetos y distinguir colores sin necesidad de que necesite pedir ayuda a terceros garantizándole autonomía y bienestar emocional.

Este proyecto aborda el tema de inclusión de nuevas tecnologías para mejorar la calidad de vida de personas con discapacidad visual. Apoyándonos en Inteligencia Artificial, creamos un sistema capaz de asistir al usuario sin necesidad de que este tenga que estar dependiendo de terceros.

Para cumplir este objetivo entrevistamos personas con ceguera, tanto de nacimiento o por alguna enfermedad, para generar un sistema a medida de sus necesidades.

1.2. Descripción general:

Nuestro sistema se compone de dos componentes principales:

- Sistema de reconocimiento visual: este va colocado en el antebrazo del usuario y se encarga de tomar la foto, procesarla y dar una respuesta a través de un auricular. Además, cuenta con pequeños motores que van a vibrar dependiendo de los colores predominantes de la foto para darle un feedback al usuario.
- Sistema de lectura cerebral: Este es un headset que tiene un sensor apoyado arriba de la ceja del usuario que permite monitorear su actividad cerebral. Cuando este genera un doble parpadeo intencional envía una señal al sistema de reconocimiento visual para sacar la foto.

Gracias a la implementación de un sensor cerebral permitimos conectar el sistema electrónico al usuario de manera no invasiva. En caso de que el usuario no se sienta cómodo con el sensor cerebral se puede implementar un botón o sensor muscular como disparador.

1.3. Alcance:

Las personas que sufren una discapacidad visual, total o casi total, que no les permite poder interactuar con el entorno haciendo uso del sentido de la vista es de aproximadamente 1.000.000 de personas en Argentina.

Nuestro foco se centra en Buenos Aires, específicamente en CABA y GBA Sur, ya que nos permite hacer un seguimiento efectivo de las personas que usen nuestro sistema, además de que se encuentran posibles aliados estratégicos como la Asociación de Ayuda al Ciego (ASAC).

1.4. Segmento de usuario:

El segmento de usuario que buscamos son personas con una discapacidad visual total o casi total que tengan una necesidad de poder manejarse de manera autónoma debido a que sienten frustraciones al no poder desenvolverse en su día a día de manera cómoda ya que no poseen información visual de lo que está pasando.

Los beneficios que “Ojo de Van Gogh” otorga a sus usuarios son:

- Capacidad de leer textos que no están adaptados en braille. Por ejemplo: etiquetas de productos, libros, etc.
- Capacidad de reconocer objetos que no pueden distinguirse por su forma al tacto.
- Retroalimentación a la hora de interactuar con colores a través de vibraciones y sonidos. Esto se fundamenta en que las entrevistas con personas ciegas nos dijeron que les genera una gran angustia sentirse excluidos de la sociedad al no poder manejarse con colores.
1.5. Captura del proyecto

Uno de los integrantes de nuestro equipo trabajando con el sistema de Reconocimiento de Colores, Textos y Objetos. En la mano tiene la cámara de la Raspberry Pi Zero W con la cual se saca las fotos para el reconocimiento.

Uno de los integrantes de nuestro equipo trabajando con el sistema de vibración de colores.


1.6. Diagrama en bloques
1.7. Resultado Conseguido
- Para reconocer objetos hemos usado como ejemplo, la siguiente imagen:

El resultado fue el siguiente:


- Para reconocer el color hemos usado como ejemplo, la siguiente imagen:


El resultado fue el siguiente:


- Para reconocer el texto hemos usado como ejemplo, la siguiente imagen:

El resultado fue el siguiente:

2. Software
2.1. Información técnica:

Para lograr el objetivo que nos propusimos, decidimos utilizar una Raspberry Pi Zero W ya que nos permite trabajar con la Inteligencia Artificial de Google (Google Vision API) en el lenguaje Python.

Google Vision API nos ofrece:

- Detección de textos
- Detección de objectos
- Detección de colores predominantes en imagen (en RGB)

Estas características de Google Visión API nos permite tener una base sólida y no lidiar con el desarrollo de una IA desde cero.

Las imágenes se toman a través de una Pi Camera la cual está diseñada para funcionar perfectamente en una Pi Zero W, que cuenta con el puerto de la pi camera, haciendo uso de Raspbian OS.

Una vez que tenemos la información hacemos uso de la librería “os” de Python que nos permite interactuar directamente con la terminal de Linux y controlar el puerto de audio para hacerle llegar la información a la persona mediante un auricular.

Todo esto es importante controlarlo y que se haga solo cuando el usuario quiera, para generar eso tenemos un sensor cerebral que se encarga de monitorear la actividad electromagnética del cerebro. En el momento que el usuario genera un doble parpadeo intencional envía un valor analógico mayor a 400 al Arduino
NANO que nos permite procesar esa información para comunicarle a la Raspberry Pi Zero W que debe sacar una foto e iniciar el análisis.

Para que el usuario pueda elegir entre leer texto, reconocer objetos o detectar colores colocamos un switch de 3 posiciones donde se puede alternar que es lo que se busca saber.

2.2. Diagrama de Arquitectura
En este se definen las clases padres e hijas del código de reconocimiento de colores, textos y objetos. También se muestra las conexiones entre la Raspberry Pi Zero W, el Arduino Nano y Mindwave.


2.3. Detección de texto:

Para procesar la imagen y extraer los textos que tiene, conectamos a la API de Google Vision y le enviamos el contenido de la imagen usando JSON:

Luego que tenemos la respuesta de la API, debemos procesarla con Pandas para quedarnos con el texto puro ya que la respuesta va a llegar con datos, útiles únicamente para el desarrollador, que confundirían al usuario final.

2.4. Detección de objetos:

Para procesar la imagen y extraer los objetos que tiene, conectamos a la API de Google Vision y le enviamos el contenido de la imagen usando JSON:

Luego que tenemos la respuesta de la API, debemos procesarla con Pandas para quedarnos con los objetos ya que la respuesta va a llegar con datos, útiles únicamente para el desarrollador, que confundirían al usuario final. La API nos va a ofrecer una variable llamada score que es un float entre 0 y 1 indicando cuanta confianza tiene la IA de que el nombre del objeto es correcto, y en el caso de que sea de menos de 0.65 lo descartamos.

Además, también creamos una función que analiza la posición X, Y del objeto para dar una orientación de donde está el mismo.


2.5. Detección de colores:

Para procesar la imagen y extraer los colores predominantes que tiene, conectamos a la API de Google Vision y le enviamos el contenido de la imagen usando JSON:

La API nos va a pasar una lista de colores en RGB ya que no puede clasificarlos por nombres.

Puede ser que la API detecte varios colores que ocupen poquísimo espacio en la imagen y no tiene sentido decirlos, por lo tanto, los descartamos. La información de cuanto espacio ocupa en la imagen se haya en el float pixel_fractions que varía entre 0 y 1.


Una vez que tenemos valores RGB los procesamos con Pandas para que compare con un dataset de valores RGB y sus respectivos nombres. La función realiza un query a nuestra tabla de colores y busca cual es el color con valores de RGB más similares a la respuesta de la API.

2.6. Detección de ondas cerebrales:

Para la programación del Mindwave se eligió usar Arduino IDE ya que es más cómodo utilizar el entorno de Arduino IDE ya que usa el conocido C ahorrando tiempo de aprender nuevos lenguajes.

El usuario se va a colocar el headset que va a estar configurado, mediante comandos AT, para conectar al Ojo de Van Gogh por Bluetooth donde un Arduino NANO procesara la información.

Primero debemos medir los valores de actividad cerebral que hay en el momento ya que los picos eléctricos cuando se está relajado son diferentes a cuando se está estresado. Una vez que tenemos estos valores definimos que el umbral de activación es 2 veces el valor de actividad cerebral en reposo.

En la anterior imagen se ve como calculamos el checksum para verificar que el emisor y el receptor estén sincronizados.

Luego medimos la actividad cerebral:


Una vez esta calibrado, se corre en loop infinito la función de activación que está constantemente midiendo el payload de la actividad cerebral y si supera el umbral envía la orden a la Raspberry Pi Zero W de que se parpadeo dos veces.

### 3. Sistema Embebido

3.1. Raspberry Pi Zero W

Elegimos utilizar la Raspberry Pi Zero W ya que tiene una gran variedad de características que hicieron más fácil la construcción del proyecto, su conectividad y su potencia nos permite usar el lenguaje Python y utilizar la inteligencia artificial de Google visión. También la utilizamos por sus características físicas, ya que al ser de un tamaño reducido en comparación con las demás nos permite simplificar el tamaño del equipo.

Características técnicas:

En este caso tenemos un dispositivo con las mismas características que la Raspberry Pi Zero pero que además incorpora el módulo de conectividad Cypress CYW43438, que le agrega conectividad Wi-Fi y Bluetooth, que consiste en:

- LAN inalámbrica 802.11 b / g / n
- Bluetooth 4.1
- Bluetooth de baja energía (BLE)
Al igual que el Pi Zero, también tiene:
- Procesador Broadcom BCM2835 @ 1Ghz ARM 11
- 512 MB de RAM
- Puertos Mini HDMI y USB On-The-Go
- Alimentación micro USB
- Cabezal de 40 pines compatible con HAT
- Vídeo compuesto y reiniciar encabezados
- Conector de cámara CSI
3.2. Arduino Nano

Arduino Nano, es una placa pequeña adaptada para trabajar con placas prototipos, que está basada en el microcontrolador ATmega328 (Arduino Nano 3.x).

La placa Arduino está diseñada de tal manera que es muy fácil para los principiantes comenzar con los microcontroladores. Esta placa especialmente es compatible con la placa de pruebas, es muy fácil de manejar las conexiones. Tiene la misma funcionalidad que el Arduino Duemilanove, pero es más pequeño en tamaño. Sólo difiere en que Funciona a través de un USB mini-B en lugar de uno estándar.

Su pequeño tamaño y facilidad de uso hizo que eligiéramos esta placa.

Sus características técnicas son:

- Microcontrolador Arduino ATmega328
- Arquitectura, AVR
- Voltaje de operación, 5 V
- Memoria flash,32 KB
- SRAM 2 KB
- Velocidad del reloj 16 MHz
- Pines de E/S analógicas, 8
- EEPROM,1 KB
- Corriente continua por pin entrada salida, 40 mA (Pines de E/S)
- Voltaje de entrada, 7-12 V
- Pines de E/S digitales, 22
- Salida PWM, 6
- Consumo de energía, 19 mA
- Tamaño de la placa de circuito impreso,18 x 45 mm
- Peso, 7 g
3.3. Atmega 328


El ATmega328 es un microcontrolador de un solo chip creado por Atmel en la familia megaAVR (más tarde Microchip Technology adquirió Atmel en 2016). Tiene un núcleo de procesador RISC de 8 bits de arquitectura Harvard modificado.

Hoy el ATmega328 se usa comúnmente en múltiples proyectos y sistemas autónomos donde se requiere un microcontrolador simple, de bajo consumo y bajo costo. Tal vez la implementación más común de este chip es en la popular plataforma Arduino, en sus modelos Uno y Nano.

Características técnicas:

El microcontrolador AVR RISC de 8 bits de Atmel combina:

- Memoria flash ISP de 32 KB con capacidades de lectura durante la escritura
- 1 KB EEPROM
- 2 KB SRAM
- 23 líneas de E/S de uso general
- 32 registros de trabajo de propósito general
- 3 temporizadores/contadores flexibles con modos de comparación, interrupciones internas y externas
- USART programable en serie,
- Una interfaz serie de 2 hilos orientada a bytes
- Puerto serie SPI
- Convertidor A/D de 6 canales de 10 bits (8 canales en paquetes TQFP y QFN/MLF)
- Temporizador de vigilancia programable con oscilador interno y cinco modos de ahorro de energía seleccionables por software.
- El microcontrolador funciona entre 1,8-5,5 voltios.
- El microcontrolador logra un rendimiento que se aproxima a 1 MIPS por MHz.
3.4. Sistemas Brain Computer Interface (BCI)

Es una tecnología que se basa en la adquisición de ondas cerebrales de una persona para luego ser procesadas e interpretadas por una máquina u ordenador. Establecen un nuevo camino para interactuar con tecnología mediante nuestro pensamiento, ya que estas interfaces permiten transformarlo en acciones reales en nuestro entorno.

Podemos decir que el principal objetivo de estos sistemas es dar un uso a esta tecnología de manera asistida para aquellas personas con discapacidades o en situación de dependencia. También pueden servir de ayuda como técnica para la mejora de la comunicación y control de personas con afasia o apraxia.

Tipos de BCI

Podemos dividir los sistemas BCI en tres grupos diferentes:

- Activo: se caracteriza por poder controlar de manera consciente y voluntaria un sistema BCI, independientemente de los eventos externos.
- Reactivo: el control de la aplicación está directamente relacionado con un estímulo externo que, indirectamente, modela la actividad cerebral.

- Pasivo: se deriva del procesamiento de señales cerebrales arbitrarias y sin ninguna intencionalidad por el usuario. La información recogida se utiliza para saber nuestro estado cognitivo, como nuestros niveles de atención, relajación, etc.
Los sistemas endógenos se basan en el reconocimiento de patrones cerebrales sin la necesidad de un estímulo externo, sino se producen por la voluntad del usuario. Como ejemplo de este proceso es el uso de ritmos beta para el control de un dispositivo cuando el usuario imagina o intenta realizar movimientos.

Los sistemas exógenos, a diferencia de los anteriores, basan su control a estímulos externos y se obtiene la respuesta cerebral de los mismos. Un ejemplo de estos dispositivos sería el determinar la dirección de la mirada o la postura del usuario para obtener una respuesta cerebral.

Aplicaciones de sistemas BCIs

Al realizar un sistema BCI, deben quedar claramente definidos los objetivos sobre los cuales se lo va a efectuar, y cuáles deben ser las limitaciones sobre el mismo. Las áreas principales en las que actualmente son aplicables este tipo de sistemas son:

- Mejorar calidad de vida personas con grave discapacidad motora
- Aumento de la autonomía e independencia
- Control de dispositivos del entorno, manejo de prótesis, sillas de ruedas, herramientas de comunicación.
- Rehabilitación cognitiva
3.5. NeuroSky Mindwave Mobile 2 EEG

La elección del aparato capaz de leer ondas cerebrales, con el cual se realizará el sistema BCI, es crucial, ya que en función de las características de este se podrá diseñar un sistema más o menos potente en función de la información recibida.

Por esto, nos decantamos hacia el NeuroSky MindWave, que es una diadema que recoge la actividad eléctrica del cerebro y divide la señal según la frecuencia en diversos tipos de ondas, lo que nos permite inferir en nuestro estado mental. El registro de dicha actividad se hace con la configuración de referencia común, dado que solo tenemos un único canal y el electrodo esta referenciado con el potencial de nuestra oreja.

Es capaz de leer, principalmente, el estado de meditación (medido por las ondas alfa / theta) o atención/concentración (medido por las ondas beta / gamma) que nuestro cerebro emite y detectar cuando la persona realiza un parpadeo

Aspectos importantes:

- Es capaz de leer los cuatro ritmos cerebrales más importantes (beta/alfa/tetha/delta).
- Incluye los algoritmos eSense para estados de atención/meditación.
- Dispone de conexión inalámbrica.
- Es muy ligero y cómodo.
- Tiene la capacidad de hacer lecturas de EMG (electromiografía)
- Tiene la capacidad de detectar el parpadeo.

Por todos estos motivos hemos elegido el NeuroSky MindWave para la realización de nuestro sistema BCI.

La estructura es de un material plástico duro. Se adapta cómodamente a la cabeza y se puede regular su tamaño. El sensor primario se apoya en la frente y requiere de un cierto ajuste para adaptarlo a la cabeza de cada usuario.

Se conecta por radiofrecuencia a través de un stick USB, y funciona con la mayoría de los modernos sistemas operativos (Windows XP o posterior, Mac OS X 10.6.5 o posterior). La vida de la batería es de unas 8/10 horas con una sola pila AAA. En la siguiente tabla podemos observar algunas especificaciones:

En cuanto al resto de las aplicaciones, debido a la naturaleza del sensor del MindWave, sólo dependen de tres tipos de variables utilizadas de una manera más o menos útil según el uso que el usuario quiera darles. Estas variables son:
- Concentración / no-concentración
- Meditación / no-meditación
- Parpadeo
El parpadeo será una utilidad muy importante para nuestro proyecto ya que con esta variable se le da las indicaciones al sistema.
Detección del parpadeo

Los datos captados con el casco Mindwave pueden fluctuar mucho y el resultado no ser el esperado. Para la validación del resultado se ha usado el parpadeo.

El simple hecho de parpadear no es indicativo de un estado mental o de una onda cerebral concreta, pero como se ha comentado con anteriormente, es un potencial por acción muscular, es decir, una señal detectada por el electrodo producida por la contracción del músculo frontal.
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

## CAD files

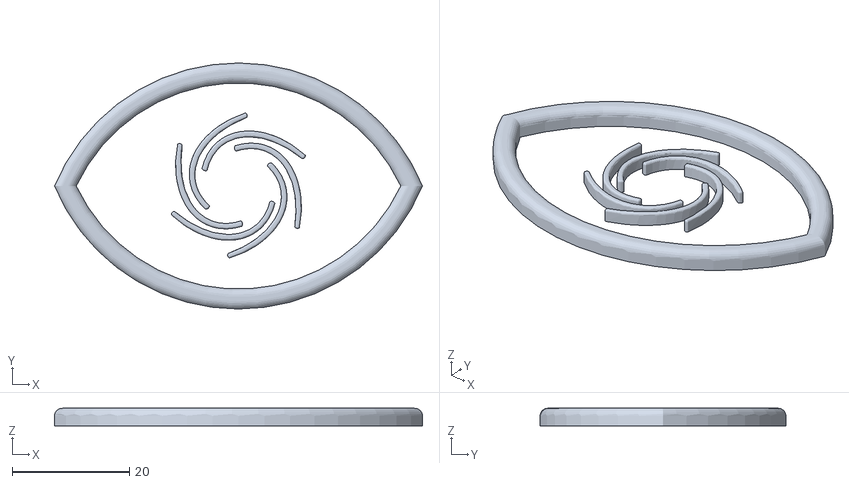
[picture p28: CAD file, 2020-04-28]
estructuras_3D/Logotipo3D/logo_ojo_de_van_gogh_CAD/Ojo_de_Van_Gogh.stl
62.8 x 42.0 x 3.00

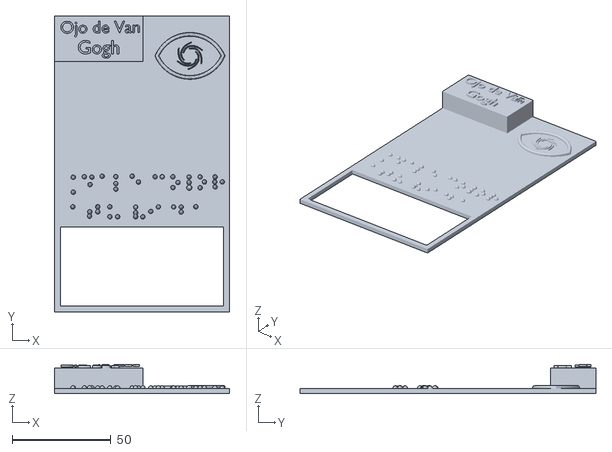
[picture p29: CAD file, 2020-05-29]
estructuras_3D/pcb_case/Case_placa_parte_2.stl
88.8 x 150.0 x 14.7

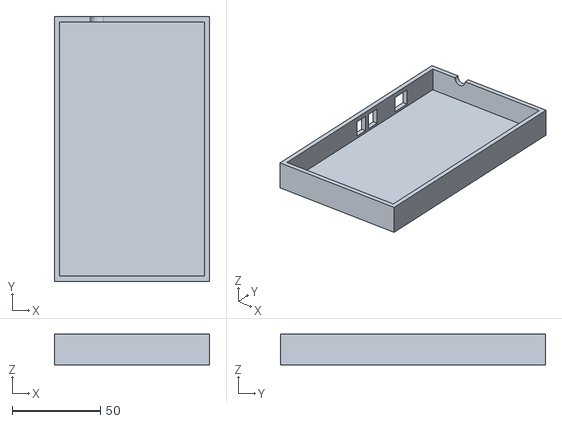
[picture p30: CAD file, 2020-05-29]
estructuras_3D/pcb_case/Case_placa_parte_1.stl
88.0 x 150.0 x 17.5

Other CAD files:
estructuras_3D/pcb_case/caja full.dwg
docs/Cosas_utiles/Rotulo-A4-AutoCAD/Formato-A4-Rotulo-iram_(1).dwg
modulo_de_carga/Diseño_de_estructura/Dibujos en AutoCAD 2007/cargador parte 1.dwg
estructuras_3D/pcb_case/caja parte 3 (tapa).dwg
modulo_de_carga/Diseño_de_estructura/Dibujos en AutoCAD 2007/cargador parte 2.dwg
estructuras_3D/pcb_case/caja parte 1.dwg
modulo_de_carga/Diseño_de_estructura/Dibujos en AutoCAD 2007/cargador de baterias.dwg
estructuras_3D/pcb_case/caja parte 2.dwg
modulo_de_carga/Diseño_de_estructura/Dibujos en AutoCAD 2007/cargador parte 3.dwg
estructuras_3D/pcb_case/Case_placa.dwg
estructuras_3D/Logotipo3D/logo_ojo_de_van_gogh_CAD/Ojo_de_Van_Gogh.dwg
estructuras_3D/pcb_case/CaseTapaConLogo.blend

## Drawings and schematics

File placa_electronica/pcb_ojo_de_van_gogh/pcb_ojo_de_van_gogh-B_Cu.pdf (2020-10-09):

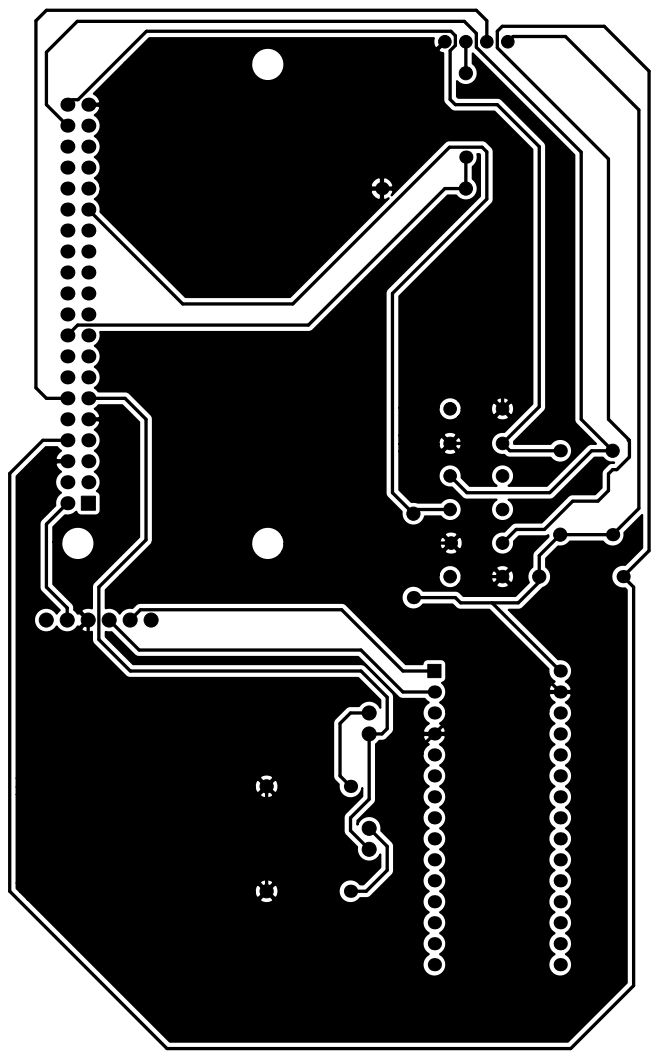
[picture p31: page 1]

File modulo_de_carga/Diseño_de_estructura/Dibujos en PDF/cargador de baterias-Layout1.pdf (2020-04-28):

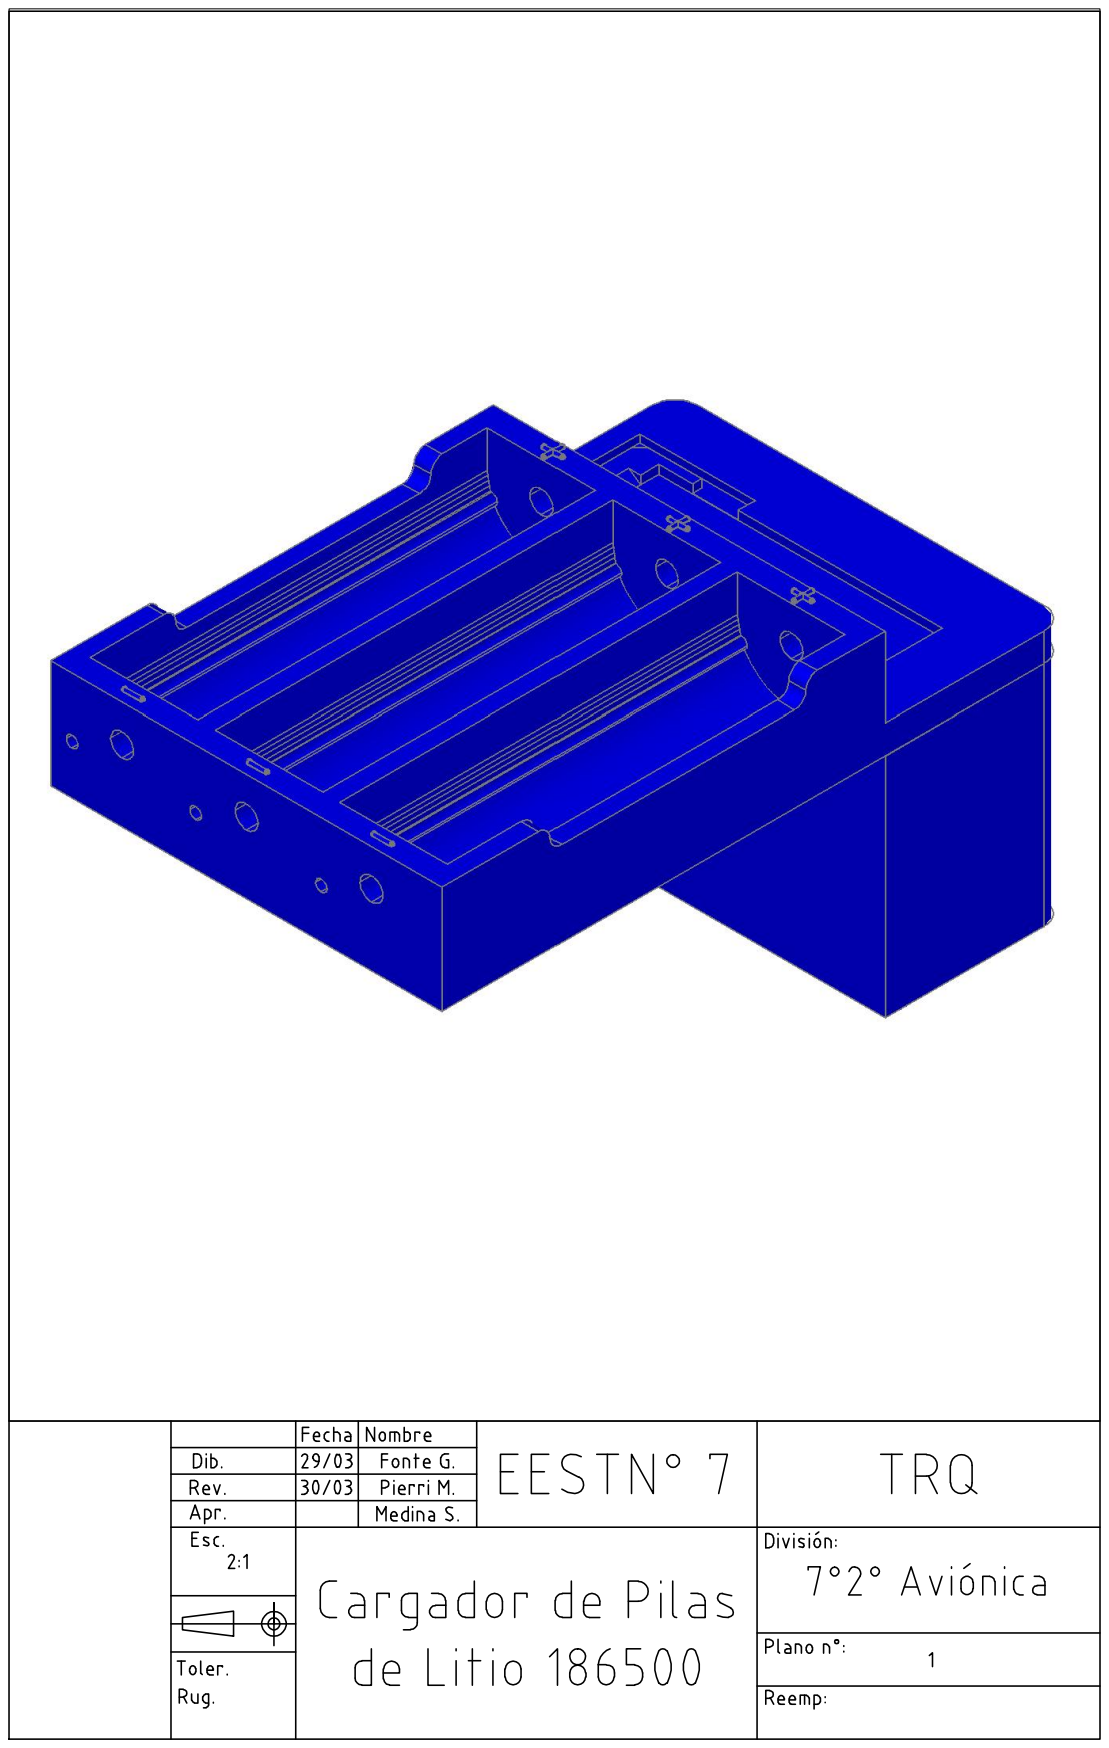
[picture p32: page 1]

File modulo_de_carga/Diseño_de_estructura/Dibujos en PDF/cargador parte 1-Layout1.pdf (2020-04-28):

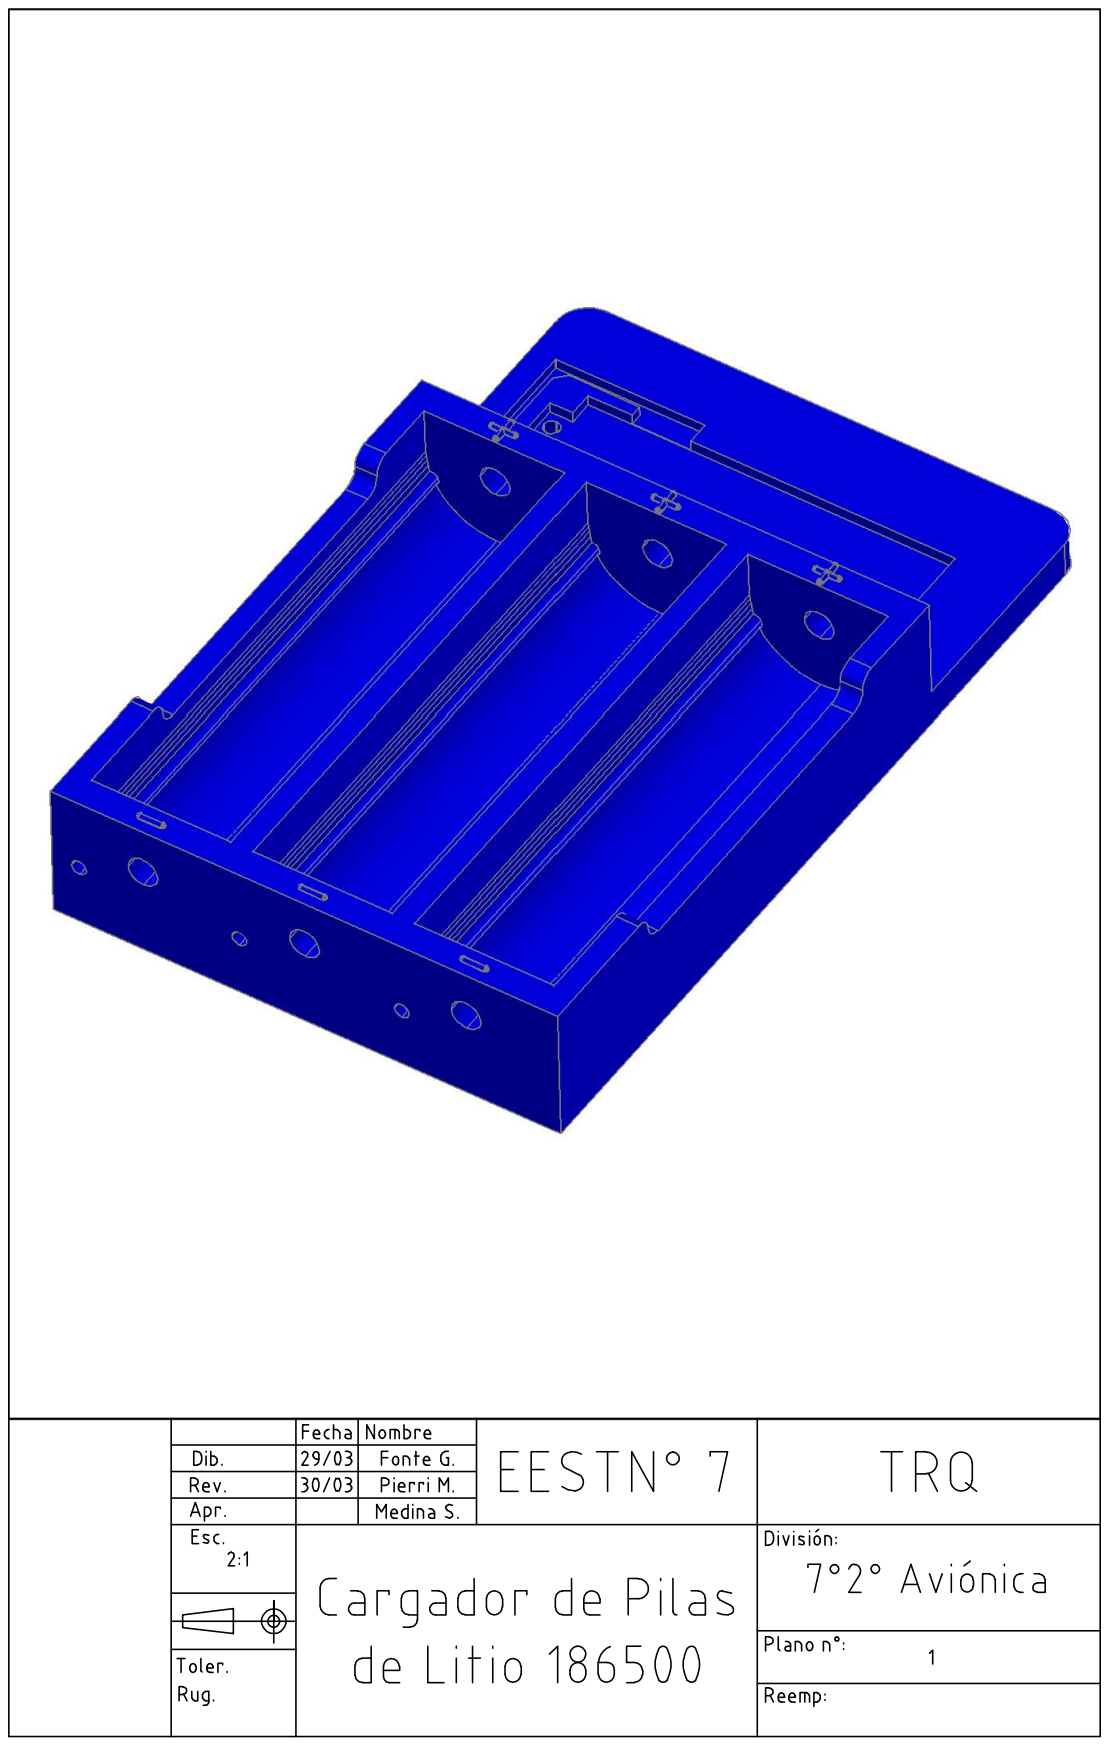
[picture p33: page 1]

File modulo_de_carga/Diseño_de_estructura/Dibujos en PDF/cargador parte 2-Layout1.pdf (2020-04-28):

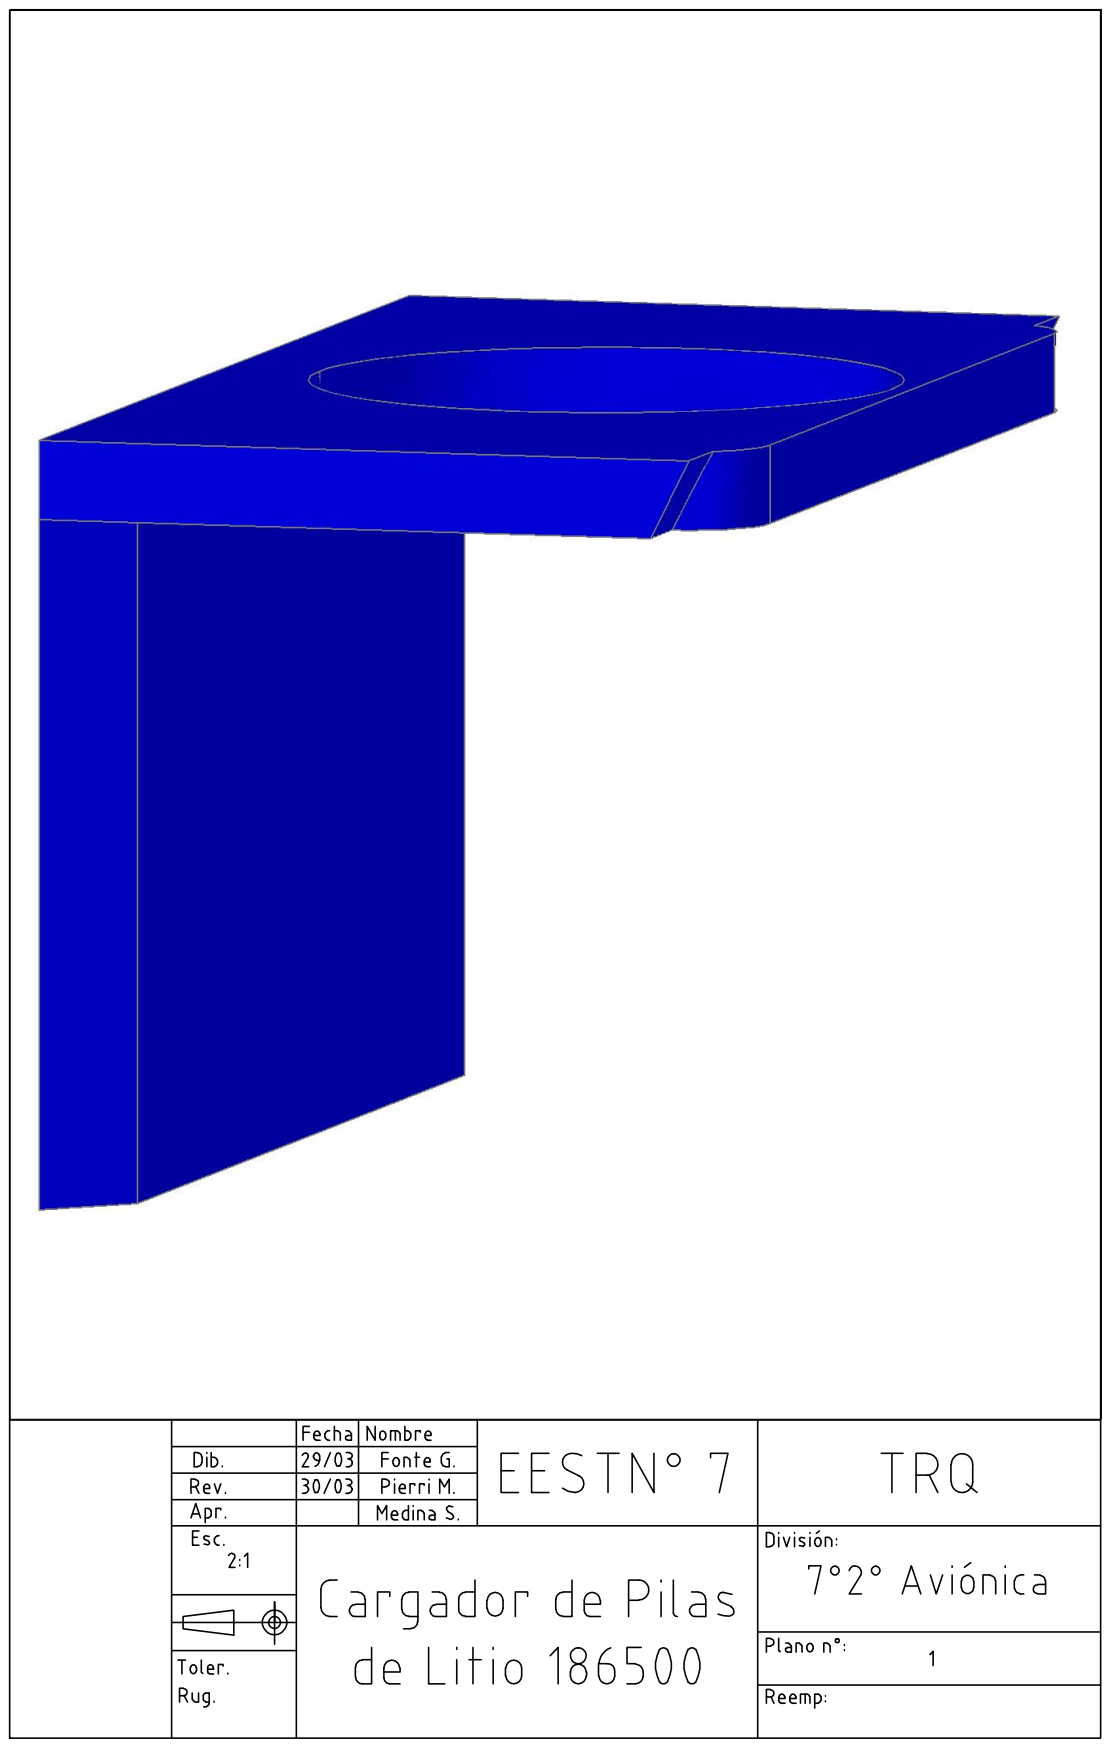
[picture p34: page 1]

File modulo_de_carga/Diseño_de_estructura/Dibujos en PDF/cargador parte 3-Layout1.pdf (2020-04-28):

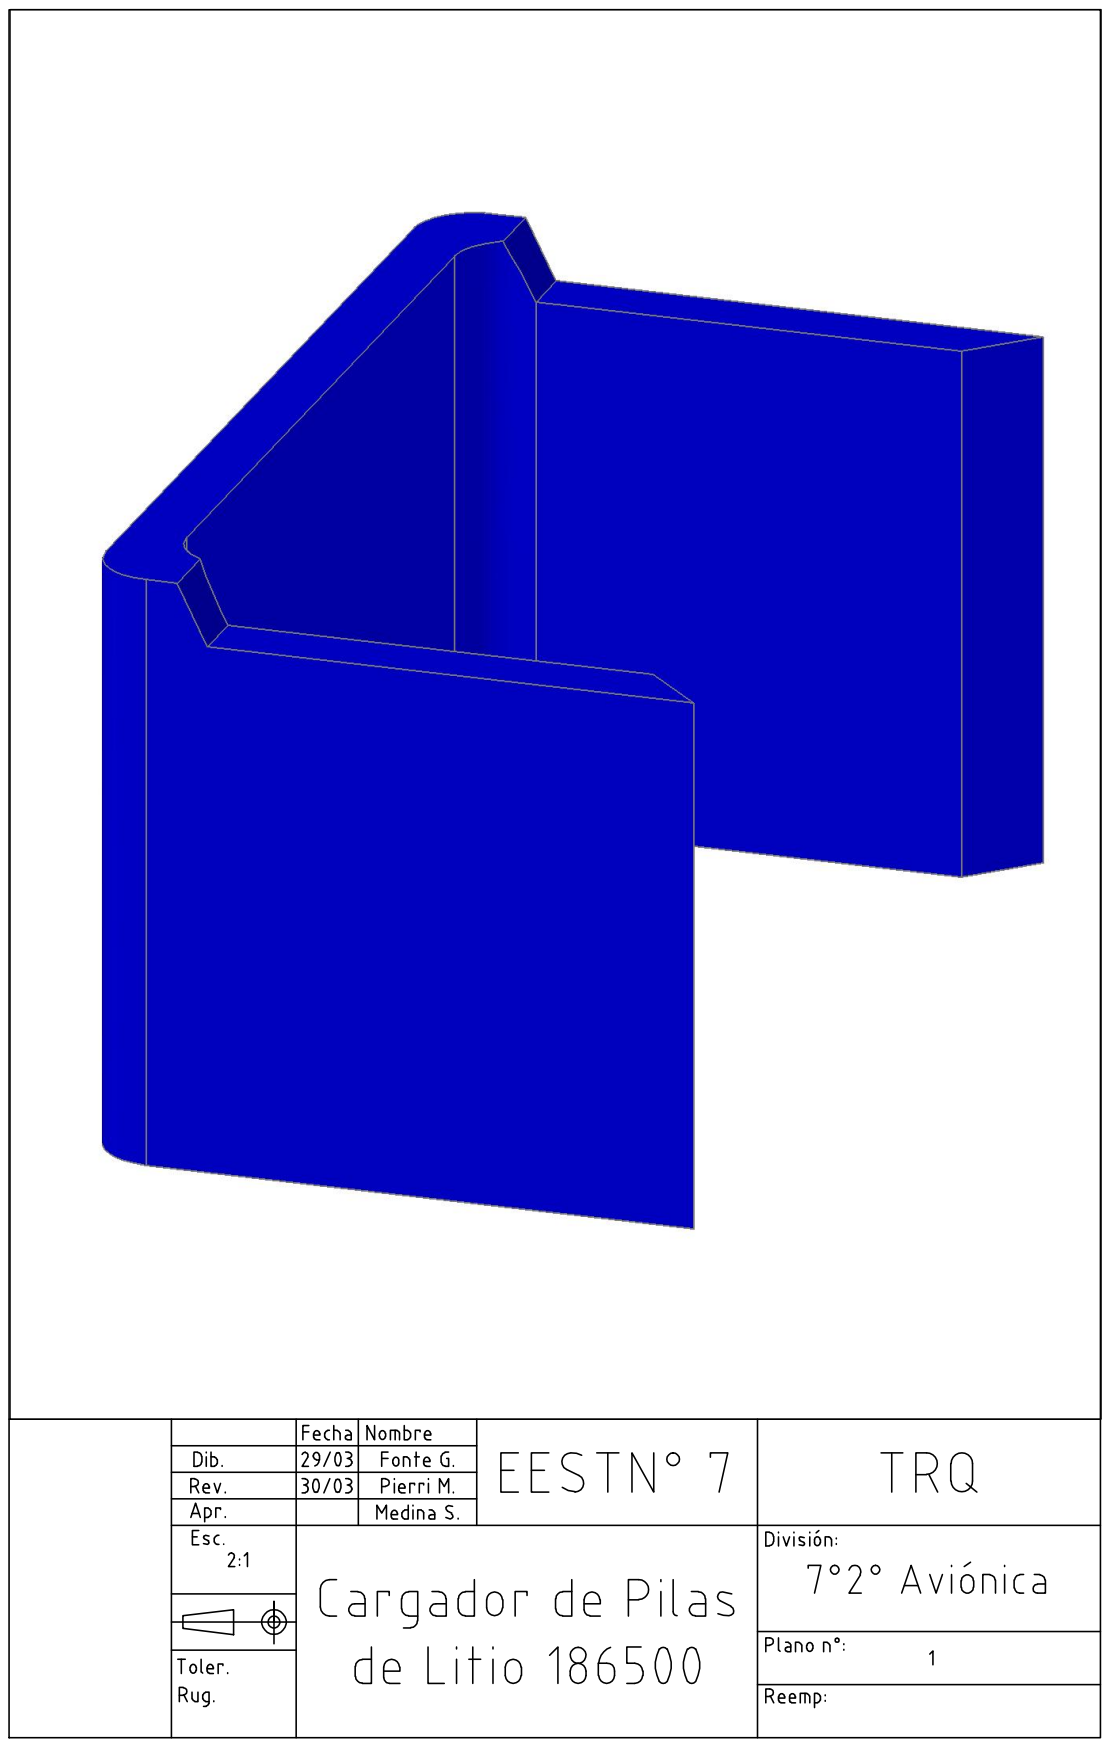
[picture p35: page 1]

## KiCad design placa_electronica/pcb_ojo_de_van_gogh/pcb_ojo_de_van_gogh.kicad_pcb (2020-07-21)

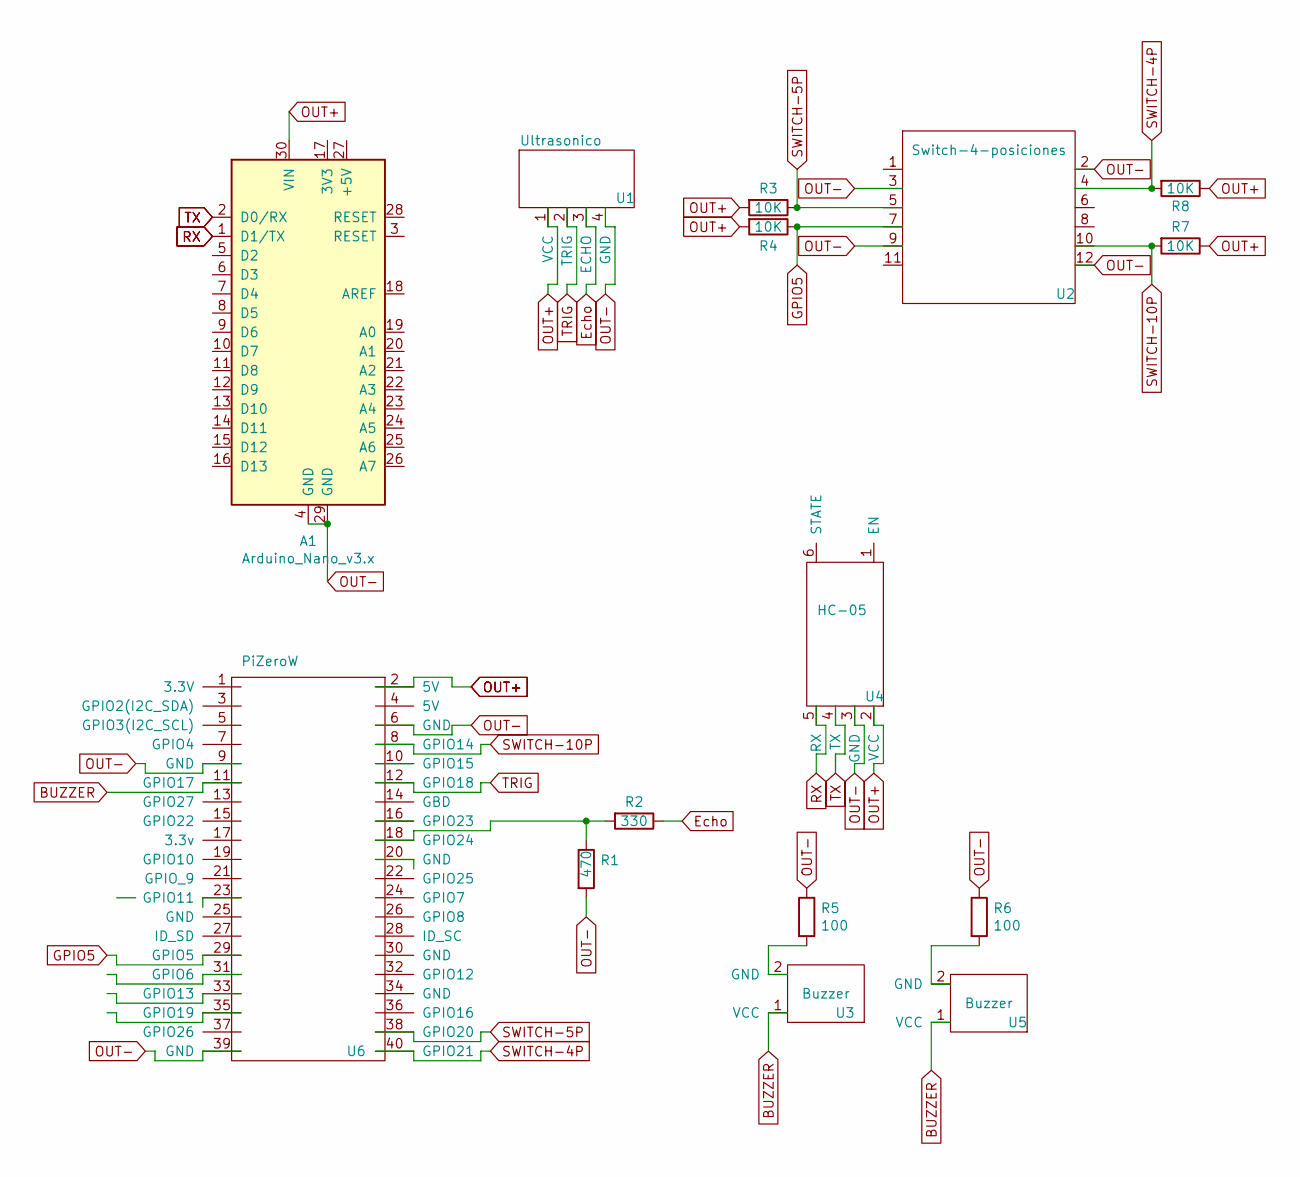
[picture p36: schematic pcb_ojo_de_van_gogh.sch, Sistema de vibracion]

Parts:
A1: Arduino_Nano_v3.x; Arduino_Nano
R1: 470; R_Axial_DIN0207_L6.3mm_D2.5mm_P10.16mm_Horizontal
R2: 330; R_Axial_DIN0207_L6.3mm_D2.5mm_P10.16mm_Horizontal
R3, R4, R7, R8: 10K; R_Axial_DIN0207_L6.3mm_D2.5mm_P10.16mm_Horizontal
R5, R6: 100; R_Axial_DIN0207_L6.3mm_D2.5mm_P10.16mm_Horizontal
U1: Ultrasonico
U2: Switch-4-posiciones; Switch_4_posiciones
U3, U5: Buzzer; Vibrador
U4: HC-05
U6: PiZeroW; Raspberry_Pi_Zero_Socketed_THT_FaceDown_MountingHoles

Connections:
BUZZER: U3.1 (VCC), U5.1 (VCC), U6.11 (GPIO17)
Echo: R2.1, U1.3 (ECHO)
GPIO5: R4.1, U2.7, U6.29 (GPIO5)
unnamed: R1.1, R2.2, U6.18 (GPIO24)
unnamed: R5.2, U3.2 (GND)
unnamed: R6.2, U5.2 (GND)
OUT+: A1.30 (VIN), R3.2, R4.2, R7.1, R8.1, U1.1 (VCC), U4.2 (VCC), U6.2 (5V)
OUT-: A1.4 (GND), A1.29 (GND), R1.2, R5.1, R6.1, U1.4 (GND), U2.2, U2.3, U2.9, U2.12, U4.3 (GND), U6.6 (GND), U6.9 (GND), U6.39 (GND)
RX: A1.1 (D1/TX), U4.5 (RX)
SWITCH-4P: R7.2, U2.4, U6.40 (GPIO21)
SWITCH-5P: R3.1, U2.5, U6.38 (GPIO20)
SWITCH-10P: R8.2, U2.10, U6.8 (GPIO14)
TRIG: U1.2 (TRIG), U6.12 (GPIO18)
TX: A1.2 (D0/RX), U4.4 (TX)

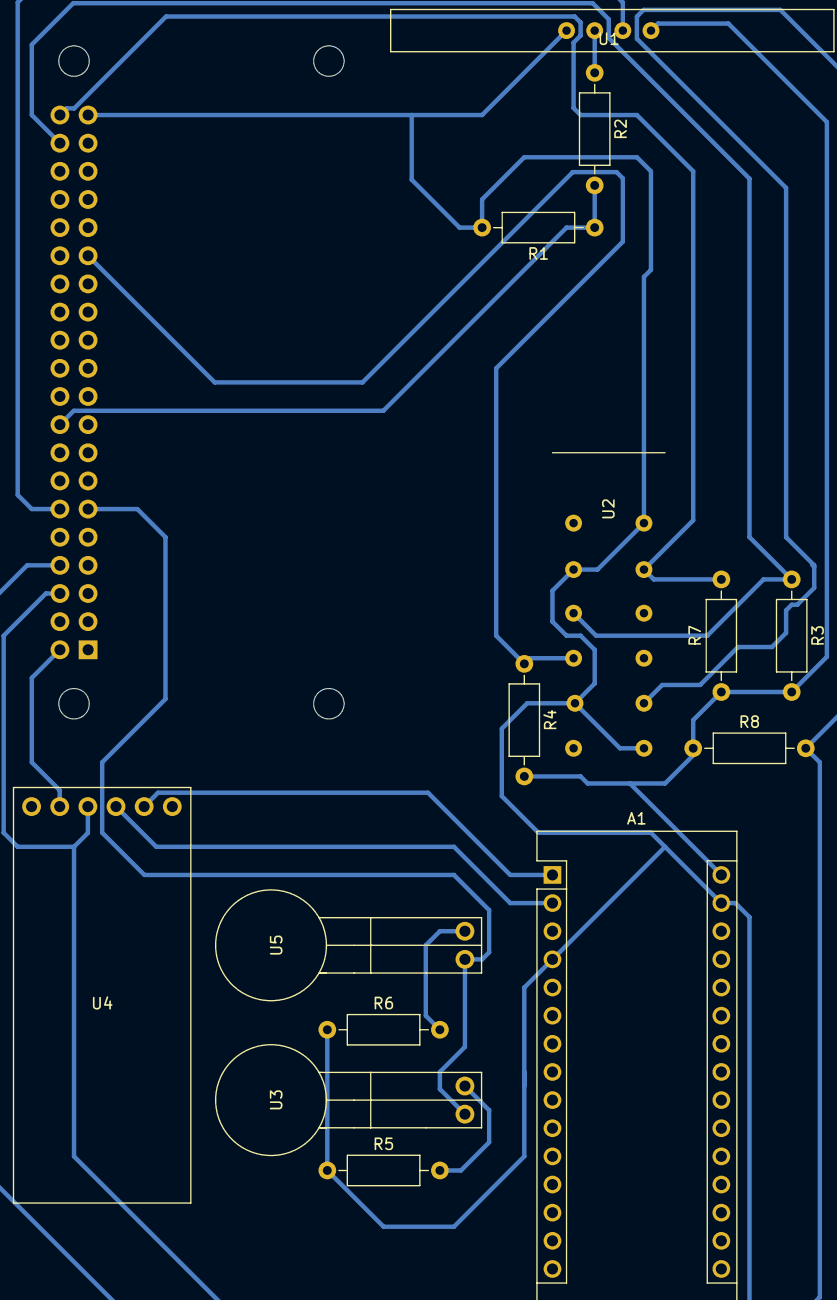
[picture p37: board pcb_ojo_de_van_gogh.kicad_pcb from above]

Board: 2 copper layers, 15 parts (1 on the bottom side), 14 nets.

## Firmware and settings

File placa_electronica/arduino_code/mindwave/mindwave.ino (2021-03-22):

//                                                         //
//    Program       : Mindwave with Arduino                //
//    Interfacing   : HC-05 Bluetooth Module               //
//    Output        : Eye Blink Control LED                //
#include "mindwave.h"


#define BAUDRATE 57600
#define LED 5
#define Theshold_Eyeblink 110
#define EEG_AVG 70


int Plength;

Mindwave mindwave(
    BAUDRATE,
    LED,
    Theshold_Eyeblink,
    EEG_AVG);

void setup()
{
  Serial.begin(BAUDRATE); // USB

  pinMode(LED, OUTPUT);
  for (int h = 0; h < 10; h++)
  {
    Serial.println("Empezo el void setup");
  }

  mindwave.Esperar_al_mindwave();

  Serial.println("Empezo a calibrar");

  mindwave.Calibrar_Sensor();
}

void loop() // Main Function
{
  if (mindwave.ReadOneByte() == 170) // AA 1 st Sync data
  {
    if (mindwave.ReadOneByte() == 170) // AA 2 st Sync data
    {
      Plength = mindwave.ReadOneByte();
      if (Plength == 4) // Small Packet
      {
        mindwave.Small_Packet();
      }
      else if (Plength == 32) // Big Packet
      {
        mindwave.Big_Packet();
        Serial.println("BigPacket");
      }
    }
  }
}

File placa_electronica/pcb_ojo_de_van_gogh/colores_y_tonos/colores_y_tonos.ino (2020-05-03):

const int buzzer=9;
int tono;
void setup() {
  Serial.begin(9600);
  Serial.println("Escribe el color: verde, rojo, azul");
}

void loop() {
if(Serial.available()){ //si llega informacion por Serial
   tono=Serial.read();    //leo y guardo en tono

   //Si es 1 hago tal ruido
     if(tono=='1'){
      //le agregue este for para que se repita 4 veces
      for(c = 0, c <= 4, c++) {
        tone(buzzer,440);
        delay(1000);
        noTone(buzzer);
        delay(100);
     
        Serial.println("Está sonando el color: verde");
      }
      c = 0;  
    }
    //Si es 2 hago tal ruido
    if(tono=='2'){
    
      for(c = 0, c <= 4, c++){
        tone(buzzer,880);
        delay(1000);
        noTone(buzzer);
        delay(1000);
        Serial.println("Está sonando el color: rojo");
      }
     c = 0;
     }
  //Si es 3 hago tal ruido
     if(tono=='3'){
      for(c = 0, c <= 4, c++){
        tone(buzzer,2000);
        delay(1000);
        noTone(buzzer);
        delay(2000);
        Serial.println("Está sonando el color: azul");
      }
      c = 0;
     }   
     
     Serial.println("Escribe el color: verde, rojo, azul");
  }
}

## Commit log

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2020-04-27 Se agrego el sript de testeo para el reconocimiento de color, hasta ahora todas las funciones se ejecutan correctamente, exeptuando la de JSON que no guarda los datos correctamente
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2020-04-28 Se Creo la carpeta de Diseño_de_estructura, dentro de la misma hay:
    - Dibujos de la estructura del cargador en AutoCAD
    - Dibujos de la estructura del cargador pasado a PDF con rotulo
    - Dibujo del logotipo del proyecto en 3D
    Please enter the commit message for your changes. Lines starting
    [cargador de baterias.dwg, cargador parte 1.dwg, cargador parte 2.dwg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]
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2020-04-28 se agrego el diagrama de conexion en KiCAD y las librerias que tiene este esquematico como dependencias
    [Cargador.sch]
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2020-04-28 se creo la carpeta de cosas utiles que tiene el logo y el rotulo en A4 para AutoCAD
    [Formato-A4-Rotulo-iram_(1).dwg]
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2020-05-03 se agrego la carpeta con las plaquetas y esquematicos
    [VIbrador.kicad_pcb, VIbrador.sch]
2020-05-03 Se creo la carpeta de 3D-model-kicad donde se guardan los archivos .step que sirven para que el visor de la placa 3D se vea como se ve. Actualmente ya la placa esta lista y fachera. Si alguien mas ab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
    [VIbrador.kicad_pcb]
2020-05-03 se agrego a la carpeta de campo lo que se hizo en la semana del 12/04 al 19/04 (rgb a hsv y mudar la pag)
    [VIbrador.kicad_pcb]
2020-05-03 Se agrego lo que hicimos dele dia 19/04 al 25/04 (solucionamos wordpress y teniamos problemas del responsive design)
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2020-06-24 Bases de datos con query que pregunta color
    [Tabla_colores.csv]
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2020-06-25 Carpeta librerias
    Aca adentro van a estar las librerias y todo va a juntarse en el main.py
    [Tabla_colores.csv, Tabla_colores.xlsx]
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2020-06-25 Se creo un enum para tener codigo mas legible
    [Tabla_colores.csv, Tabla_colores.xlsx]
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2020-06-25 Se reviso cada color
    Vi todos los colores y hay algunas que son medios raros y puse revisar para que determinemos en cual lo dejamos. Agregue un color negro que es el 141
    [Tabla_colores.csv]
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2020-06-29 Revert "Descarga blanco y negro para el query y responde automatico"
    This reverts commit baa662c412eeff4ea01aaabb11147e5cda370124.
2020-06-29 Se soluciono un problema de compatibilidad
    [Tabla_colores.csv]
2020-06-29 Revert "Revert "Descarga blanco y negro para el query y responde automatico""
    This reverts commit f3a12d64798f4e77203efd43c21752bec15663d3.
2020-06-29 Se puso un if que detecta cuando el query esta vacio. En este caso hace un append al dataframe original para agregarle el nuevo color y deja un mensaje de que hay que clasificarlo. Machine learning p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
    [Tabla_colores.csv]
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2020-07-03 s agrego where que permite fitlrar la nfo con una funcon que devuelva true o false
    [Tabla_colores.csv]
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2020-07-04 Se agrego el codigo de color.py y mas colores en la tabla
    Probe varios colores obtenidos del codigo de color.py y cambie algunas cosas en el codigo de query.py para que cada vez que haya un dataframe vacio me lo guarde y quede en la tabla
    [Tabla_colores.csv]
2020-07-04 Se actualizo los colores con sus Nombres, subnombres y Hex
    Le agregue los nombres a todos los colores , su apodo y el hexadecimal por si queremos buscarlo en algun momento. Hay algunos que se llaman igual pero son diferentes valores de rgb, pero visualmente 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
    [Tabla_colores.csv]
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2020-07-09 Se agrego sort_values para ordenar la tabla
    Se intento agregar un codigo de ordenamiento por mezcla pero no se pudo y se hizo por sort_values
    [Tabla_colores.csv]
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2020-07-10 Se agrego para que se actualice el valor de ID
    Primero se ordena el valor id del pandas y luego se recorre la tabla guardando cada valor segun su posicion .
    [Tabla_colores.csv]
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2020-07-14 Update Tabla_colores.csv
    Se tradujo la base de datos del color al idioma español, con la finalidad de ahorrarle al script la funcion de traduccion (TextBlob).
    [Tabla_colores.csv]
2020-07-16 Cambios en los TX/RX y buzzer
    Ahora el pin para contorlar el buzzer es el GPIO11 de la raspberry. Ademas el tx/rx del bt va al arduino que le pasa los datos a la raspberry por cable usb. Se borro el modulo para las pilas porque vamos a usar un cargador portatil
    [VIbrador.sch]
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2020-07-21 Conexiones PCB
    Quedo conectado todo feo y como el orto pero esta conectado que es mejor que nada despues hay que revisar todas las conexiones y dejarlas facheras
    [VIbrador.kicad_pcb]
2020-07-21 PCB Terminado
    Se actualizaron algunos pines de la raspberry ya que al principio se eligio al azar los que iban conectados a el switch y se fue viendo como convenia mas
    [VIbrador.kicad_pcb, VIbrador.sch]
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2020-08-01 Se creo una tabla de colores
    Se encontro una tabla con 860 valores, con sus nombres , hexadecimal y rgb. Se le agrego la columna de id en excel.
    [colores.csv]
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2020-08-08 Entrevista de problema a osvaldo
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2020-08-09 Se corrigio el error
    Se corrigio el error de que no existe mas rgb_to_name_query y se lo cambio por el def que existe : rgb_to_name
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2020-09-21 Se corrigieron algunos errores
    Se agrego return a los llamados de metodo para obtener los valores y se corrigio un error de tabulacion en el metodo obtener_nombre_color y se borraron las librerias os e io que estaban demas
2020-09-21 Se corrigieron algunos errores
    Se agrego la clase de google.cloud y se creo la variable de la respuesta de la api
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2020-10-07 Carpeta estructuras_3D
    Se creo esta carpeta para almacenar los diseños en autoCAD de la caja que contiene la plaqueta
    [caja full.dwg, caja parte 1.dwg, caja parte 2.dwg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]
2020-10-07 Logo 3D
    Este logo 3D es para colocar en nuestros productos y establecer la marca
    [Ojo_de_Van_Gogh.dwg, Ojo_de_Van_Gogh.stl]
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2020-10-07 Rename de la plaqueta
    La plaqueta se llamaba vibrador erroneamente. Paso a llamarse pcb_ojo_de_van_gogh
    [CaseTapaConLogo.blend, Case_placa.dwg, Case_placa_parte_1.stl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]
2020-10-07 Revert "Rename de la plaqueta"
    This reverts commit 4062cc4e7b224c506d507956528a24495f5cce1a.
    [CaseTapaConLogo.blend, Case_placa.dwg, Case_placa_parte_1.stl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]
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2020-10-07 Rename pcb files
    Se cambio el nombre de los archivos a pcb_ojo_de_van_gogh porque el nombre "vibrador" es anticuado
    [pcb_ojo_de_van_gogh.kicad_pcb, pcb_ojo_de_van_gogh.sch]
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2020-10-07 Carpeta auxiliar
    Los codigos que quedaron de ejemplo que mantuvimos porque nos sirvieron de guia los pasamos a una carpeta auxiliar para ver ejemplos
    [Tabla_colores.csv, colores.csv]
2020-10-07 gitignore json
    Se coloco para no enviar credenciales de Google Cloud Platform
    [Tabla_colores.csv, colores.csv]
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2020-10-08 Cosas utiles borrada
    Se borro porque no tenia nada interesante adentro
    [Formato-A4-Rotulo-iram_(1).dwg]
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2020-10-20 Se hicieron cambios en las librerias
    Se agrego que la case google vision engine está en la carpeta clases y a texto to audio se puso que el contenido se convierta en str para que no de error
    [colors_manager.py, object_manager.py, text_manager.py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]
2020-10-20 Refactoring del main
    Se cambio las importaciones de libreria por el reorden de las carpetas.
    Se puso la ubicacion del dataset de colores con decodificacion utf-8
    Se corrigio para que se tome el enum agregando value.
    Se cambiaron los nombres de los metodos viejos por los actuales
    [colores.csv]
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
